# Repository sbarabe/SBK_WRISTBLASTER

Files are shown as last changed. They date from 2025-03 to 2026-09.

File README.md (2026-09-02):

# SBK_WRISTBLASTER
Arduino firmware, electronics, and 3D-printable parts for a custom Wrist Blaster prop inspired by *Ghostbusters: Frozen Empire*.

---
Work in progress :
- 3D model V2 parts list.
- Update electronics parts list.
- Update assembly guide for PCBs : PropCore One V2, BarDrive Max28 V1, BarMeter Sx28.
- New electronic board with SMD parts to make life easier...
- Polyphonic capability : dream board with polyphonic capability and embedded SDCard reader, player, amplifier, power circuits.
  
---
**2026-09-02 UPDATE**
- Firmware release v2.0.0.
- New schematic drawing with SBK PropCore One, BarDrive MAX28 and BarMeter Sx28 PCBs.
  
---

**2026-08-06 UPDATE**
- https://github.com/sbarabe/SBK_WRISTBLASTER/blob/main/README.md
- 3D model updated to V2, see 3D model README file for details.

---

<p>
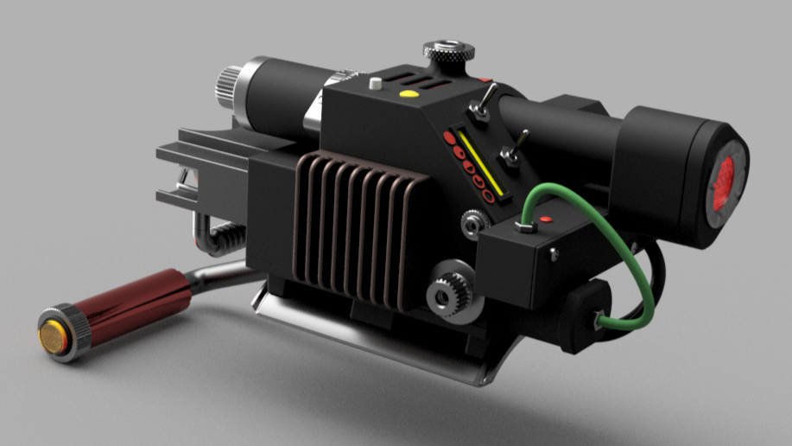
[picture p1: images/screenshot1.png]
  
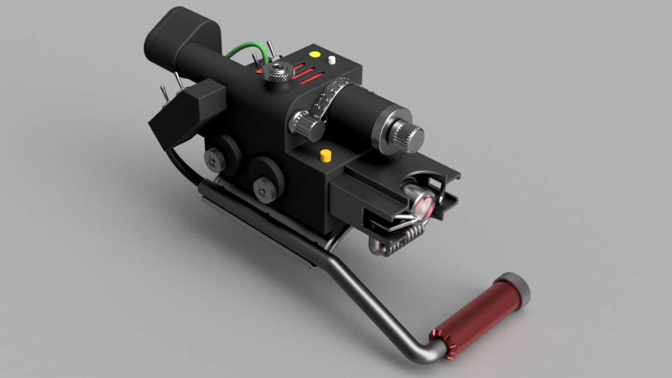
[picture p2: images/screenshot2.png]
  
</p>

Power Cell battery-pack options:

<p>
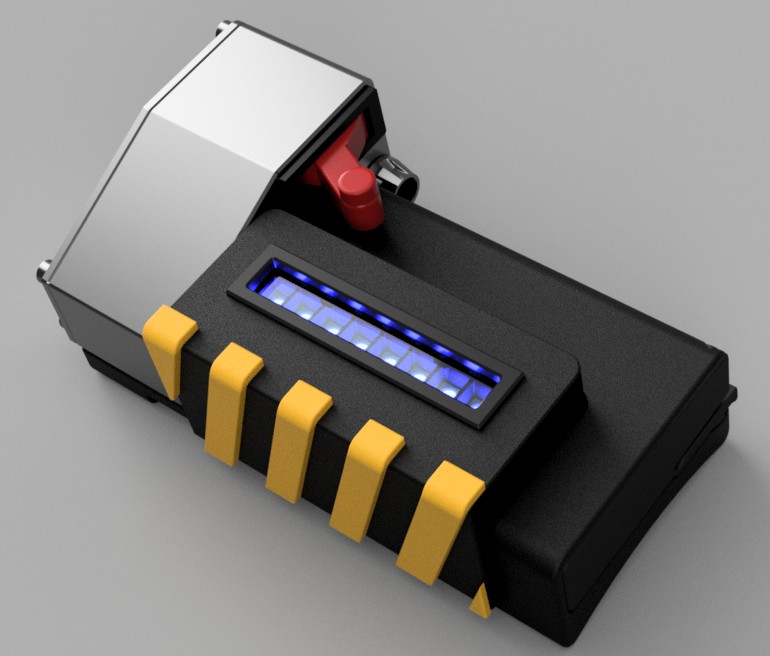
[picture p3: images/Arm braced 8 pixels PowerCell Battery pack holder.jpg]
8-pixel WS2812 Power Cell
  
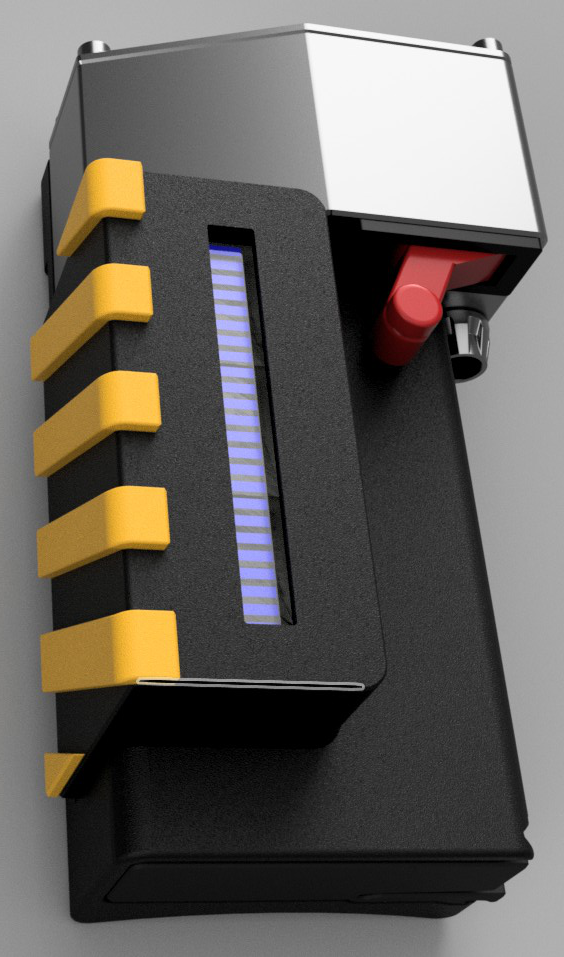
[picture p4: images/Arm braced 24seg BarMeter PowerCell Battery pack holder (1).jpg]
24-segment bar meter Power Cell
  
</p>

## Current Firmware Release

**Version 2.0.0**

This release introduces the new 2.0 engine architecture and migrates the latest firmware, configuration, and hardware definitions into the repository.

### Highlights in v2.0.0

- Revised power-up, Cyclotron, firing, overheat, venting, and shutdown sequences.
- Predefined pin mappings for several SBK controller boards, plus a custom-pin option.
- Panel bar meter support through either a MAX7219/MAX7221 or HT16K33 driver.
- Optional Power Cell using either:
  - an addressable WS2812 LED strip; or
  - a 24-segment bar meter driven by a MAX72xx or HT16K33.
- Power Cell WS2812 LEDs can share the main LED chain or use a separate output when supported by the selected board.
- Optional battery monitoring and low-battery shutdown on boards with a battery-sense input.
- Configurable switch logic, animation directions, segment mappings, potentiometers, illuminated fire button, and serial debugging.
- Support for DFPlayer communication through SoftwareSerial or the Nano Every hardware `Serial1` interface, depending on the selected board.
- Reusable Cyclotron and Power Cell animation schemes.
- External `SBK_Button`, `SBK_BarDrive`, `SBK_MAX72xx`, and `SBK_HT16K33` libraries replace the legacy bundled switch and bar-meter drivers.
- A lightweight bundled player engine replaces the external DFPlayer library dependency.
- Smoke support remains optional and experimental; it is disabled by default.

## Overview

`SBK_WRISTBLASTER_CORE` controls the prop's lighting animations, sound effects, switches, indicators, firing modes, heat simulation, and optional accessories.

The repository also includes 3D-printable parts, schematics, example sound effects, and resources for building the complete prop. The SBK PCBs are designed to fit the provided 3D model, but the firmware can also be adapted to other custom prop builds.

## Main Features

- **Sound effects:** DFPlayer Mini playback synchronized with prop states and animations.
- **Addressable lighting:** WS2812 animations for the firing tip, indicators, vent, Cyclotron, and optional Power Cell.
- **Panel bar meter:** Heat-level animation with configurable segment count, direction, and mapping.
- **Two firing modes:** Capture stream at regular Cyclotron power and burst firing at full power.
- **Heat and overheat simulation:** Heat accumulates while firing and cools while idle; extended firing triggers warning and venting sequences.
- **Party Mode:** Plays tracks stored in folder `/01` on the DFPlayer SD card.
- **Optional controls:** Volume and firing-hue potentiometers.
- **Optional battery monitoring:** Configurable battery chemistry, scaling, and low-voltage cutoff.
- **Standalone diagnostics:** The firmware can run without a working audio player, and serial debugging can be enabled in the configuration file.

## Supported Controller Configurations

Select exactly one controller definition in `SBK_WRISTBLASTER_CONFIG.h`.

> **Recommended controller:** The preferred and currently documented PCB for this firmware release is **SBK PropCore ONE Vx** (`SBK_PROPCORE_ONE_Vx`). Its schematic is available in the repository's [`Schematics`](https://github.com/sbarabe/SBK_WRISTBLASTER/tree/main/Schematics) folder. The other definitions are retained for compatibility with earlier boards or custom builds.

| Configuration | Supported MCU | Status and notes |
| --- | --- | --- |
| `SBK_PROPCORE_ONE_Vx` | Arduino Nano or Nano Every | **Preferred configuration.** Matches the currently available GitHub schematic and provides a separate WS2812 Power Cell output and battery-sense input. |
| `SBK_WRIST_BLASTER_PCB_V2` | Arduino Nano Every | Legacy board support; no dedicated Power Cell or battery-monitoring connection. |
| `SBK_WRIST_BLASTER_II_PCB_Vx` | Arduino Nano or Nano Every | Legacy board support; no dedicated Power Cell or battery-monitoring connection. |
| `SBK_PROPCORE_ONE_PLUS_Vx` | Arduino Nano Every | Alternate/extended configuration using hardware `Serial1`, a dedicated Power Cell bar meter interface, and a battery-sense input. |
| `CUSTOM_PINS_DEFINITION` | User-defined | Advanced custom builds; edit the dedicated custom section in `SBK_WRISTBLASTER_PINS_DEF.h`. |

## Hardware Requirements

> **Estimated electronics cost:** Makers sourcing the components themselves should expect approximately **$100–140 USD**, including a **7.2 V NiMH battery pack**. Actual cost depends on suppliers, shipping, component availability, and PCB quantities. This estimate excludes 3D-printing material, hardware, straps, and cosmetic parts.

See the electronic parts list in the `Resources` folder for complete details. A typical build uses:

- Arduino Nano Every.
- Genuine DFRobot DFPlayer Mini DFR0299 and a microSD card.
- Populated SBK controller PCB.
- Four miniature toggle switches, with the Intensify control optionally replaced by a push button.
- Five individual WS2812 pixels.
- Two 7-pixel WS2812 jewels.
- One 16 mm momentary fire button with a yellow LED, such as the R16-503.
- One 28-segment bar meter, such as the BL28-3000-Sx04Y.
- Compatible MAX7219/MAX7221 or HT16K33 bar meter driver hardware.
- One 2-inch, 3-5 W, 4-ohm speaker (check speaker footprint with the 3D model).
- A suitable 6–12 V power source; a 7.2 V NiMH flat pack is recommended for the provided battery holder.

Optional components include:

- One B10K potentiometer for volume **RECCOMENDED**.
- One B10K potentiometer for firing-strobe hue.
- An 8-pixel WS2812 Power Cell strip or a 24-segment Power Cell bar meter.
- Smoke and fan hardware for experimental smoke effects.

### SBK PCBs

- Main controller: **SBK Wrist Blaster PCB II** or **SBK PropCore ONE/ONE+**, according to the build.
- Common-cathode bar meter driver: **SBK BarMeter SK28 V1**.
- Common-anode bar meter driver: **SBK BarMeter SA28 V1**.
- 28-segment bar meter driver: **SBK BarDrive MAX28 V1** or **SBK BarDrive HT28 V1**.
- Optional 24-segment Power Cell bar meter and driver PCBs.

PCBs are produced in small batches and on demand. For availability, contact [SmartBuildsKits@gmail.com](mailto:SmartBuildsKits@gmail.com).

## Firmware Installation

### 1. Download the project

- Download the repository ZIP from [SBK_WRISTBLASTER](https://github.com/sbarabe/SBK_WRISTBLASTER), or clone the repository.
- Extract the files.

### 2. Install the sketch and bundled engine files

- Copy the `SBK_WRISTBLASTER_CORE` folder into your Arduino sketchbook.
- Move the bundled `SBK_WristBlaster_lib_V2_0_0` folder into the Arduino sketchbook `libraries` folder.

The final structure should resemble:

```text
Arduino/
├── libraries/
│   └── SBK_WristBlaster_lib_V2_0_0/
└── SBK_WRISTBLASTER_CORE/
    ├── SBK_WRISTBLASTER_CORE.ino
    ├── SBK_WRISTBLASTER_CONFIG.h
    └── SBK_WRISTBLASTER_PINS_DEF.h
```

### 3. Install external libraries

Using the Arduino IDE Library Manager, install:

- **Adafruit NeoPixel**
- **SBK Button**
- **SBK BarDrive**
- **SBK MAX72xx** or **SBK HT16K33**, according to the selected bar-meter driver

Install all dependencies requested by the Arduino IDE.

### 4. Configure the firmware

Open `SBK_WRISTBLASTER_CONFIG.h` and select exactly one PCB configuration:

```cpp
// Define exactly one:
// #define CUSTOM_PINS_DEFINITION
// #define SBK_WRIST_BLASTER_PCB_V2
// #define SBK_WRIST_BLASTER_II_PCB_Vx
#define SBK_PROPCORE_ONE_Vx
// #define SBK_PROPCORE_ONE_PLUS_Vx
```

Then review the remaining configuration sections for your build:

- switch and button type and logic;
- panel bar meter driver, direction, segment count, and mapping;
- WS2812 LED count and indexes;
- Power Cell type, driver, direction, and mapping;
- smoke effects, which are experimental and disabled by default;
- volume and firing-hue potentiometers;
- battery type, voltage scaling, and low-battery cutoff;
- DFPlayer volume, timing, and track durations;
- serial debugging.

> **Important:** Audio sequencing normally uses the track durations defined in `SBK_WRISTBLASTER_CONFIG.h`. Incorrect durations can desynchronize the sound and animations. BUSY-pin timing is available for experimentation but is not recommended by default.

Avoid modifying `SBK_WRISTBLASTER_CORE.ino`. For custom wiring, select `CUSTOM_PINS_DEFINITION` and edit only its dedicated section in `SBK_WRISTBLASTER_PINS_DEF.h`.

### 5. Compile and upload

- Open `SBK_WRISTBLASTER_CORE.ino` in the Arduino IDE.
- Select the board that matches the chosen controller configuration.
- Select the correct serial port.
- Compile and upload the sketch.

## Sound Effects and SD Card Setup

The provided example sound effects match the track numbers and default durations in the firmware configuration.

The DFPlayer identifies root-folder tracks by their copy order rather than reliably by filename. Start with a freshly formatted microSD card and copy the required root tracks to it one at a time, in numerical order.

Place additional music tracks in folder `/01`; these are used by Party Mode.

If you replace or edit a sound file, update its duration in `SBK_WRISTBLASTER_CONFIG.h` so the corresponding animation remains synchronized.

### Sound-effects disclaimer

The example sound effects are derived from *Ghostbusters* films and games and remain the property of their respective copyright holders. They are provided as edited examples for this fan project. You are responsible for ensuring that your use complies with applicable copyright law.

## Controls and Operation

- **Main Power:** Turns the blaster on or starts the shutdown sequence.
- **Cyclotron Power:** Starts the Cyclotron and enables regular-power Capture firing.
- **Activate:** Raises the Cyclotron to full power and enables Burst firing.
- **Fire Button:** Starts the firing sequence for the currently selected power level.
- **Intensify:** Enters or exits Party Mode. It can be configured as either a push button or a switch.
- **Party Mode navigation:** Short-press Fire for the next track; long-press Fire for the previous track.
- **Overheat:** Repeated Burst shots or a long Capture stream can trigger an overheat warning, venting sequence, and system restart.

When experimental smoke support is compiled in, hold the Fire button while the blaster is in the Power Off state to view or change the smoke-enable status. The top white indicator displays green when enabled and red when disabled.

## 3D Model Design Choices

The model aims for the rugged, prototype-like appearance of the *Frozen Empire* prop while making several practical changes:

- The Intensify control may be built as a switch because its original push-button position is difficult to reach while the blaster is worn on the right arm.
- The straps pass between the main body and the arm-brace plate, leaving more internal room for the electronics and speaker.
- The arm-brace plate is curved to accept a 3/8-inch copper-pipe handle secured through the plate holes.
- The indicator lenses use modern, readily available parts.
- The fire button includes a yellow indicator LED.
- The front knob and Clippard-valve knob can optionally control volume and firing hue.

See the README in the `3D model` folder for model-specific information and revision notes.

## Schematics

Schematics in the `Schematics` folder show the wiring for the supported SBK controller, BarDrive, and BarMeter PCBs. Confirm that the schematic revision matches your controller selection and firmware configuration before assembly.

## Demo Video

🎥 [Watch the demo video](https://drive.google.com/file/d/1tK8gQD61fCHybJHeq_SOud1DNxneKH4g/view?usp=sharing)

## Contributing

Pull requests are welcome. Please fork the repository, test your changes on the intended hardware, and describe the controller and configuration used for testing.

## License

- The firmware source files identify the code as licensed under the **MIT License**.
- The repository-level `LICENSE` file covers the remaining project material under **Creative Commons Attribution 4.0 International (CC BY 4.0)**.
- Included or referenced *Ghostbusters* media remains the property of its respective copyright holders and is not relicensed by this project.

See the repository `LICENSE` file and the headers of individual source files for the terms that apply to each item.

## Author and Collaborator

### Author: Samuel Barabé

Engineer and maker focused on embedded programming, electronics, 3D design, and immersive props.

### Collaborator: David Miyakawa

Graphic designer and *Ghostbusters* enthusiast who contributed to sound design, prop appearance, screen-inspired workflow, assembly, painting, and finishing.

## Contact and Support

- Email and PCB inquiries: [SmartBuildsKits@gmail.com](mailto:SmartBuildsKits@gmail.com)
- GitHub: [sbarabe](https://github.com/sbarabe)
- Donations: [PayPal](https://paypal.me/sbarab?country.x=CA&locale.x=fr_CA)

---

Enjoy building your Wrist Blaster!

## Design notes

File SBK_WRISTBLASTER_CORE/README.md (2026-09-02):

# SBK_WRISTBLASTER_CORE

Arduino firmware for controlling the lights, sound effects, switches, indicators, and animation sequences of the SBK Wrist Blaster replica or other custom props.

## Current Release

**Version 2.0.0**

This release migrates the firmware to the new 2.0 engine architecture:

- Reworked the core state machine, configuration, and pin definitions.
- Added reusable Cyclotron and Power Cell animation schemes.
- Replaced the legacy switch handling with the `SBK_Button` library.
- Replaced bundled bar-meter drivers with the `SBK_BarDrive`, `SBK_MAX72xx`, and `SBK_HT16K33` libraries.
- Replaced the external DFPlayer dependency with the bundled lightweight player engine.
- Updated the LED-strip, vent, firing-rod, indicator, smoke, battery-monitoring, and Power Cell engines.

The firmware retains the features introduced in previous versions, including:

- Support for multiple SBK PCB configurations and custom pin assignments
- DFPlayer Mini sound playback
- WS2812 lighting effects and animation sequences
- Panel bar-meter support using either a MAX7219/MAX7221 or HT16K33 driver
- Configurable 28-segment bar-meter mapping and animation direction
- Optional Power Cell using either:
  - An addressable WS2812 LED strip
  - A 24-segment bar meter
- Optional battery-voltage monitoring on supported boards
- Configurable switches, buttons, potentiometers, and indicator outputs
- Serial debugging
- Compile-time configuration checks

Most users should only need to modify `SBK_WRISTBLASTER_CONFIG.h`.

The main file, `SBK_WRISTBLASTER_CORE.ino`, contains the state machine and core operating logic and should normally remain unchanged.

## Supported Hardware Configurations

The following predefined pin configurations are available:

- `SBK_WRIST_BLASTER_PCB_V2`
- `SBK_WRIST_BLASTER_II_PCB_Vx`
- `SBK_PROPCORE_ONE_Vx`
- `SBK_PROPCORE_ONE_PLUS_Vx`
- `CUSTOM_PINS_DEFINITION`

The firmware supports the Arduino Nano Every and ATmega328-based Nano targets, subject to the enabled feature set and available memory.

Exactly one hardware configuration must be selected in `SBK_WRISTBLASTER_CONFIG.h`.

## Required Arduino Libraries

Install the following libraries using the Arduino IDE Library Manager:

- [Adafruit NeoPixel](https://github.com/adafruit/Adafruit_NeoPixel)
- [SBK Button](https://github.com/sbarabe/SBK_Button)
- [SBK BarDrive](https://github.com/sbarabe/SBK_BarDrive)
- [SBK MAX72xx](https://github.com/sbarabe/SBK_MAX72xx) when using a MAX72xx bar-meter driver
- [SBK HT16K33](https://github.com/sbarabe/SBK_HT16K33) when using an HT16K33 bar-meter driver

The firmware also uses the standard Arduino `Wire` and `SoftwareSerial` libraries.

The project-specific engine files are included in the `SBK_WristBlaster_lib_V2_0_0` folder.

## Installation

1. Download or clone the complete [SBK_WRISTBLASTER repository](https://github.com/sbarabe/SBK_WRISTBLASTER).

2. Copy the `SBK_WRISTBLASTER_CORE` folder into your Arduino Sketchbook folder.

3. Copy the included `SBK_WristBlaster_lib_V2_0_0` folder into your Arduino Sketchbook `libraries` folder.

4. Install the required external Arduino libraries listed above.

5. Open `SBK_WRISTBLASTER_CORE.ino` in the Arduino IDE.

6. Open `SBK_WRISTBLASTER_CONFIG.h` and select the correct PCB configuration:

   ```cpp
   // Define exactly one:
   // #define CUSTOM_PINS_DEFINITION
   // #define SBK_WRIST_BLASTER_PCB_V2
   // #define SBK_WRIST_BLASTER_II_PCB_Vx
   #define SBK_PROPCORE_ONE_Vx
   // #define SBK_PROPCORE_ONE_PLUS_Vx

7. Work through the configuration file and adjust the available options to match your build, including:

   - Switch and button types and logic
   - Panel bar-meter driver type, segment mapping, and animation direction
   - Smoke-effect support—currently a beta feature that has not yet been tested with a real smoke device
   - Volume potentiometer support
   - Firing-rod hue potentiometer support
   - Power Cell type and configuration, if installed
   - Battery-voltage sensing and low-voltage protection options
   - LED indexes and animation directions
   - Sound-track durations and audio timing
   - Serial debugging

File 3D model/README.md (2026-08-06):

# SBK WRISTBLASTER 3D MODEL
---
**2026-08-06 UPDATE**

3D model updates to **V2**.
- Some interferences fixed.
- Fire Rod LEDs jewel distance from lens was adjusted for better luminosity, a LEDs holder (part #34) was created for this, Rod Box and Lens Holder were adapted too.
- Handle was corrected for 3/8 copper pipe, about 10mm outside diameter.
- Gunbox and base plate modified for last electronic PCBs version.
- Changed parts are marked as V2.
- Some previous electronics PCBs may not fit without model modifications
---
3D model for 3D printing of a *Ghostbusters: Frozen Empire* inspired Wrist Blaster replica.

The 3D model provided is part of this project: [SBK_WRISTBLASTER](https://github.com/SmartBuildsKits/SBK_WRISTBLASTER).

The SBK PCBs are specifically designed to fit this model but can also be used in other designs.

See the **3D printed parts list** and **Other parts list** for details.

I keep a small stock of non-printed parts for personal uses. If you're having trouble sourcing a specific component, feel free to reach out—I might be able to help. **Contact me via email for inquiries**.

Screenshot of PCB design Screenshot of PCB design

## License

Shield: [][cc-by]

This work is licensed under a
[Creative Commons Attribution 4.0 International License][cc-by].

[][cc-by]

[cc-by]: http://creativecommons.org/licenses/by/4.0/
[cc-by-image]: https://i.creativecommons.org/l/by/4.0/88x31.png
[cc-by-shield]: https://img.shields.io/badge/License-CC%20BY%204.0-lightgrey.svg

This means:

✅ You are free to share (copy and redistribute) and adapt (remix, transform, build upon) the material.

❌ Commercial use is prohibited without the author's consent.

✅ You must give appropriate credit and link to the original project.

For more details, see the full license text: [CC BY 4.0](http://creativecommons.org/licenses/by/4.0/).

## Contact

📧 **Email:** [SmartBuildsKits@gmail.com](mailto:SmartBuildsKits@gmail.com)

🌐 **Website:** [https://github.com/SmartBuildsKits](https://github.com/SmartBuildsKits)

## Support

💸 To keep this project and keep development going, you can **acquire a PCB** or **donate via PayPal**: [Donate via PayPal](https://paypal.me/sbarab?country.x=CA&locale.x=fr_CA).

💻 **Inquiries** can be sent to [SmartBuildsKits@gmail.com](mailto:SmartBuildsKits@gmail.com).

---

Enjoy building your wrist blaster! 🚀💥

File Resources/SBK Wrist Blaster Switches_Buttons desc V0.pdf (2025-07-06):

# SBK Wrist Blaster switches/buttons descriptions

INTENSIFY SWITCH/BUTTON:
OFF = Party Mode OFF
ON = Party Mode ON
Play music from /01 folder. You can play next with fire button short press, or previous with long press.
Party Mode only works when Power is On but Cyclotron is OFF.

ACTIVATE SWITCH:
OFF = Capture Mode
Keep firing when firing button is pressed until overheat, about 20-25 seconds.
Cooldown while not firing. Heat level displayed on bar meter : fuller the bar, hotter it is.
ON = Burst Mode
Fire a short burst when Fire Button is pressed.
You can fire rapidly 5 shots before overheating.
There is a cooldown mechanic so waiting a little between shots make it possible to fire many shots without
overheating.

CYCLOTRON SWITCH:
OFF = Cyclotron OFF
ON = Cyclotron ON

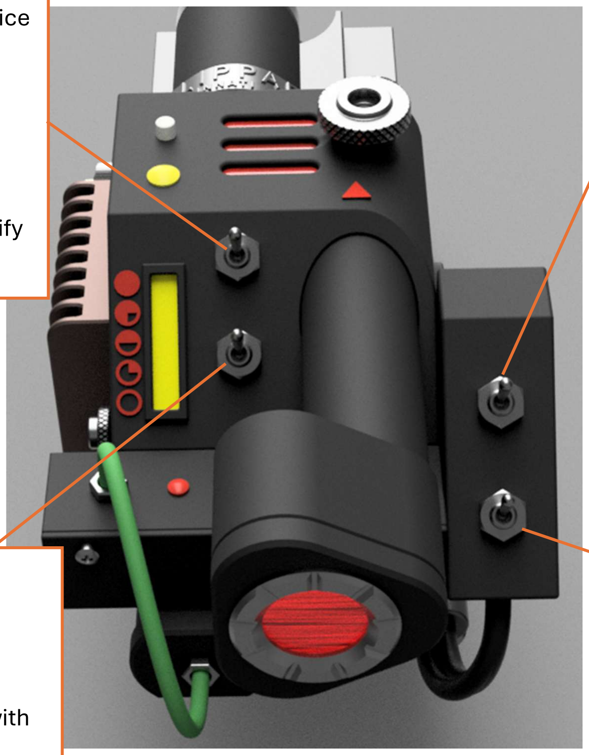
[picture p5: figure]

While cyclotron ON, you can fire with fire button. Fire type depends on Activate switch state for Capture Mode or Burst Mode.

POWER SWITCH:
(software power, not hardware)
OFF = Power OFF
While in power o, can
enable/disable optional smoke device with fire button.
ON = Power ON
Power the wrist blaster (some leds eects) but cannot fire without turning on the cyclotron.
Can goes in Party Mode with Intensify button/switch.

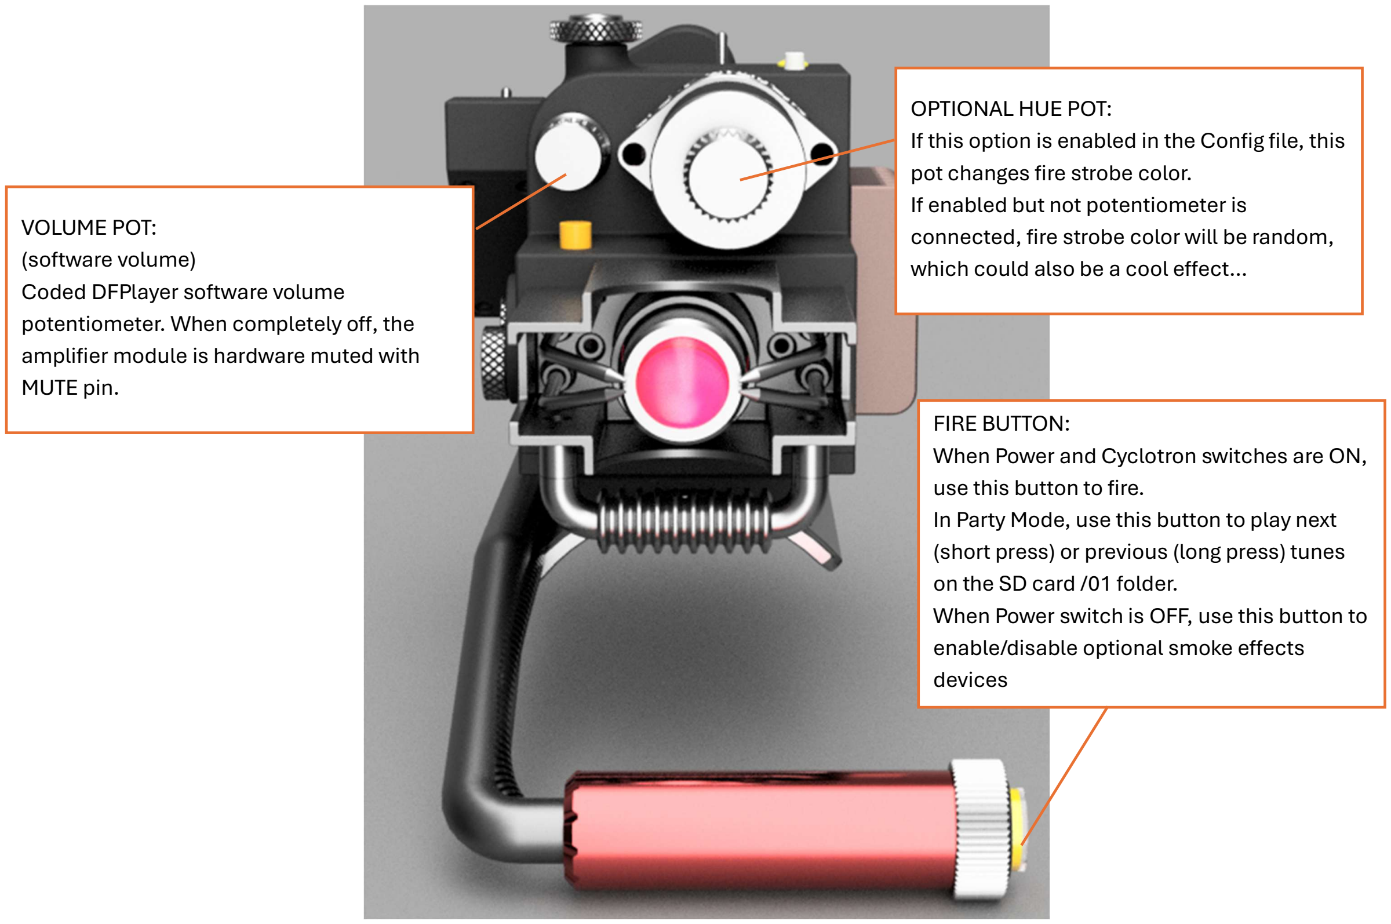
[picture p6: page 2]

VOLUME POT:
(software volume)
Coded DFPlayer software volume potentiometer. When completely o, the amplifier module is hardware muted with MUTE pin.

OPTIONAL HUE POT:
If this option is enabled in the Config file, this pot changes fire strobe color.
If enabled but not potentiometer is connected, fire strobe color will be random, which could also be a cool eect…

FIRE BUTTON:
When Power and Cyclotron switches are ON, use this button to fire.
In Party Mode, use this button to play next (short press) or previous (long press) tunes on the SD card /01 folder.
When Power switch is OFF, use this button to enable/disable optional smoke eects devices

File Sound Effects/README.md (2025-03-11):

# Sound Effects

Sound effects examples are provided for this project : [SBK_WRISTBLASTER_CORE](https://github.com/SmartBuildsKits/SBK_WRISTBLASTER_CORE). They fit the firmware track numbers and lengths defined in the config file. Each sound effect should be placed in the correct order on the Player's SD card root folder. Additional tracks can be placed in the "/01" folder of the SD card; these tracks will play in Party Mode.

**Disclaimer**: The sound effects in this project are derived from the *Ghostbusters* movies and video games, which are commonly available within the *Ghostbusters* community. These sounds are not owned by me, and the original works are copyrighted by their respective owners. The sound effects here have been edited, cut, and remixed for use in this project. No copyright infringement is intended. It is your responsibility to ensure that your use of these sound effects does not violate copyright laws.

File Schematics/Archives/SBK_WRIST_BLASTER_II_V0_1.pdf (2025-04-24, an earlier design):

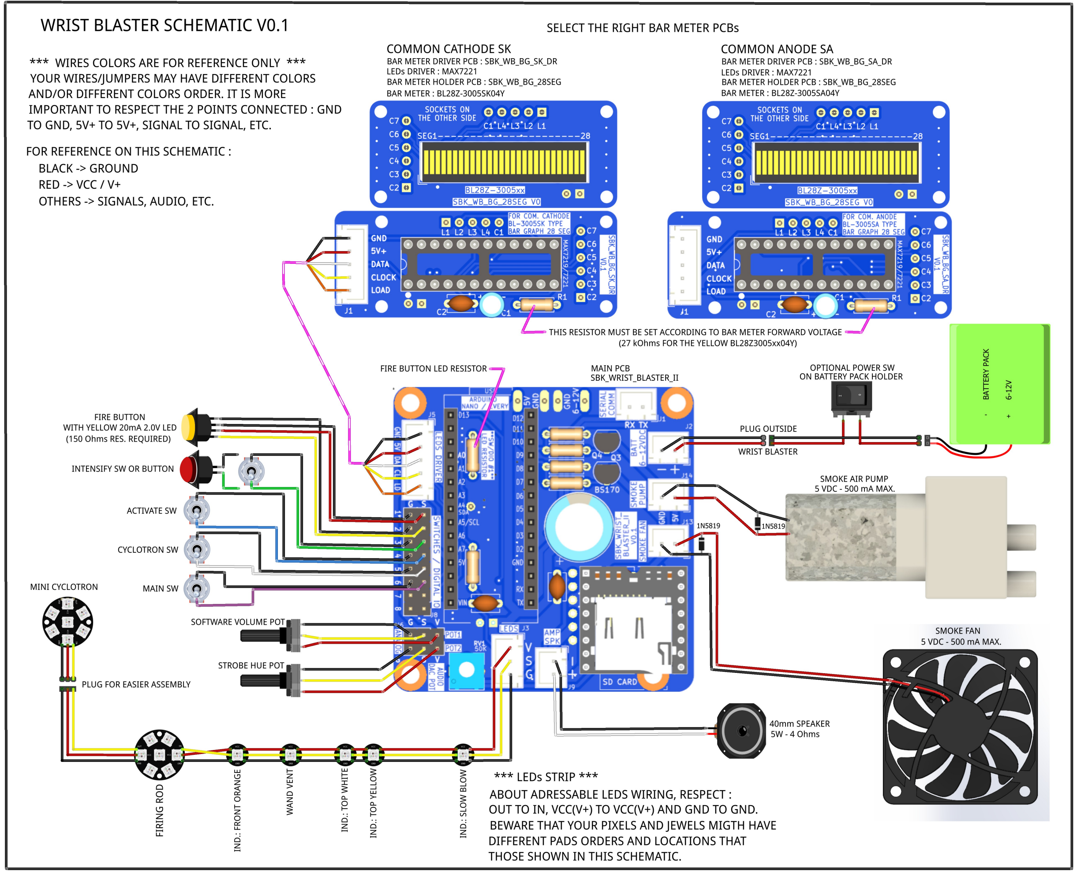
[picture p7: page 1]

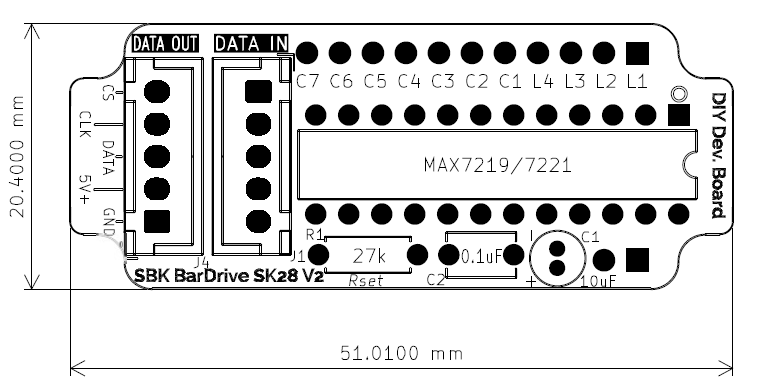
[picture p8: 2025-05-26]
Schematics/SBK PCBs/SBK BarDrive SK28 V2.png

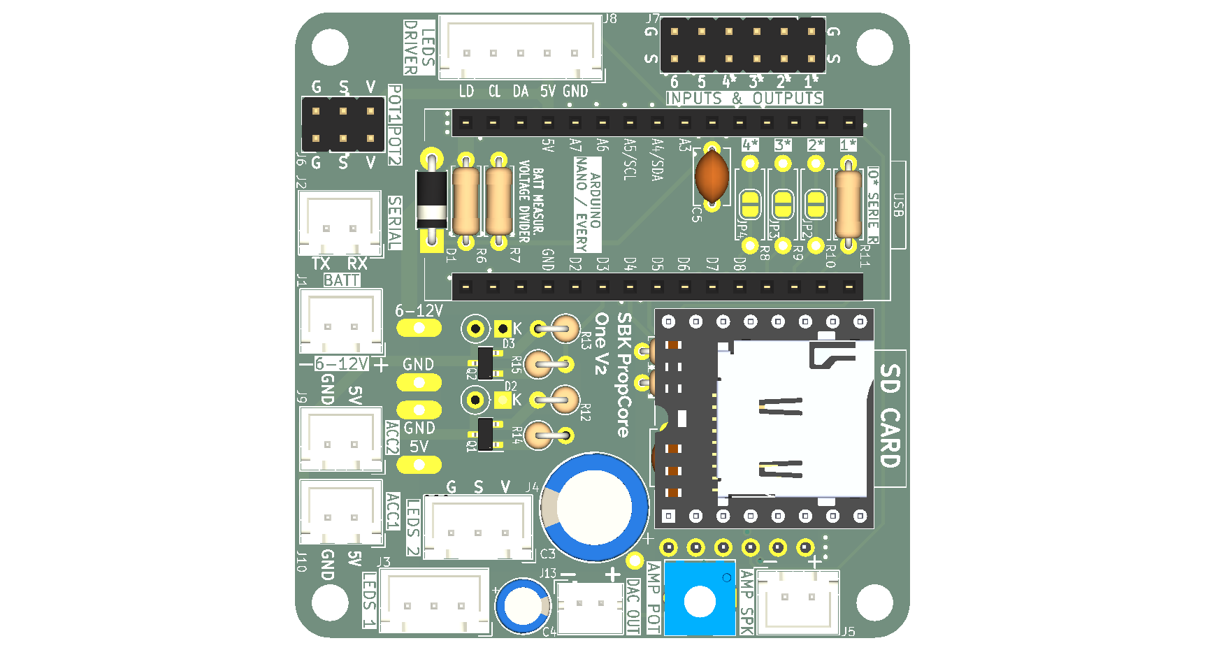
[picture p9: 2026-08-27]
Schematics/SBK PCBs/SBK PropCore One V2.png

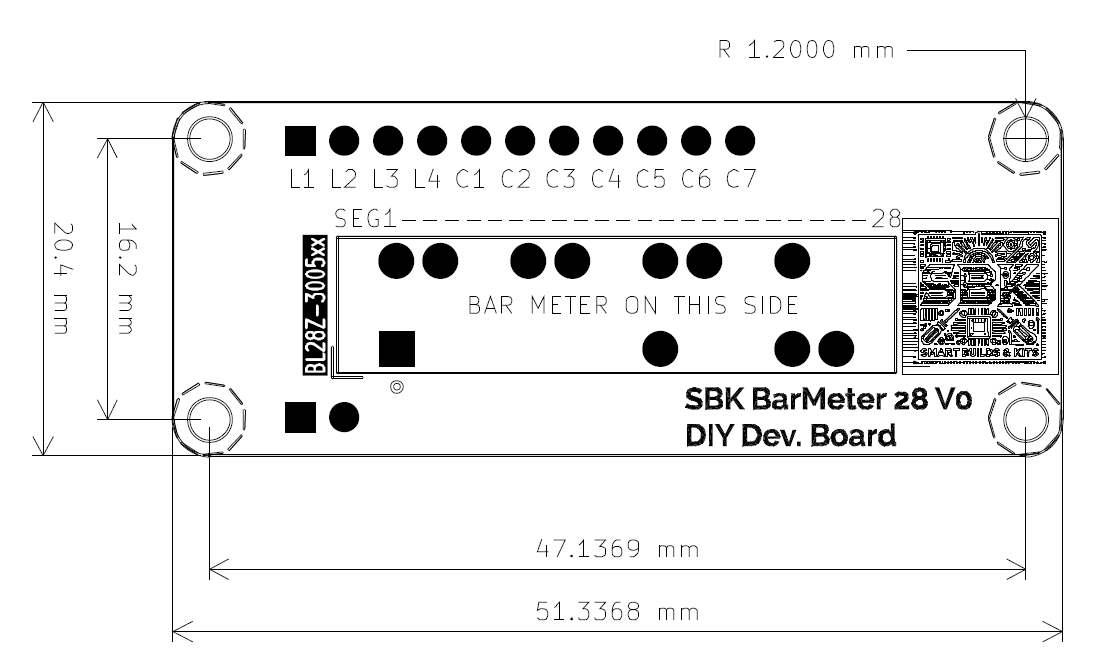
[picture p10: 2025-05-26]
Schematics/SBK PCBs/SBK BarMeter 28 V0.png

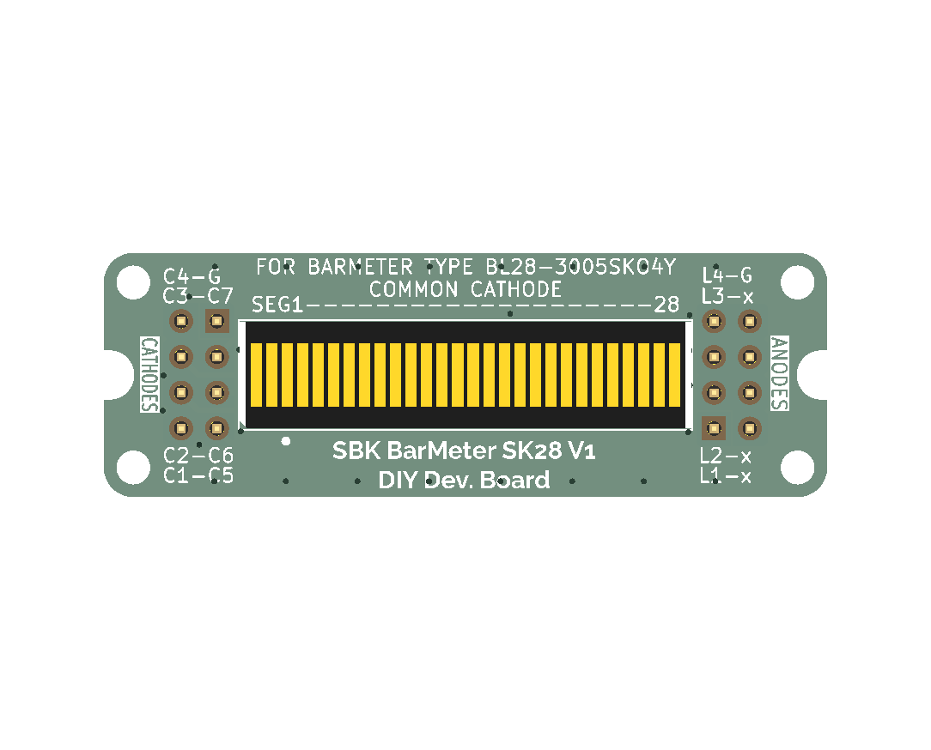
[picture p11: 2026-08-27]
Schematics/SBK PCBs/SBK BarMeter SK28 V1.png

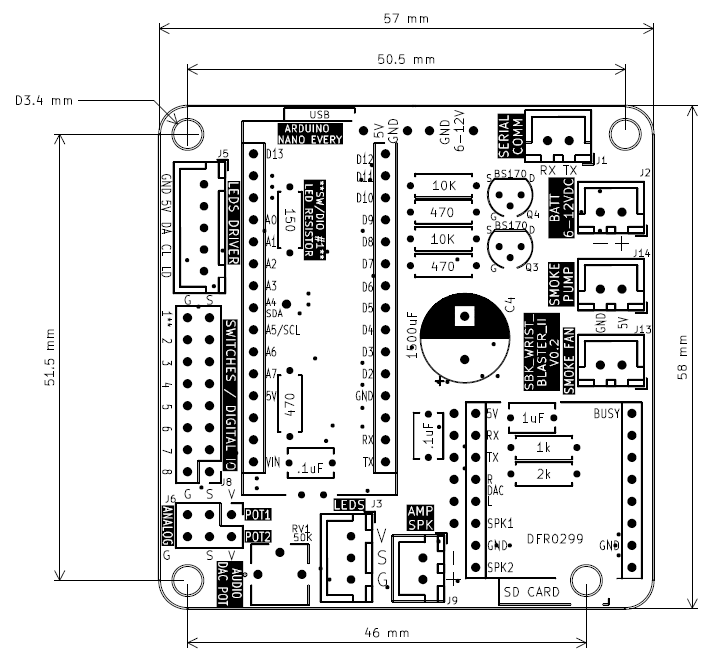
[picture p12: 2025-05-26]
Schematics/SBK PCBs/SBK_WRIST_BLASTER_II V0.2.png

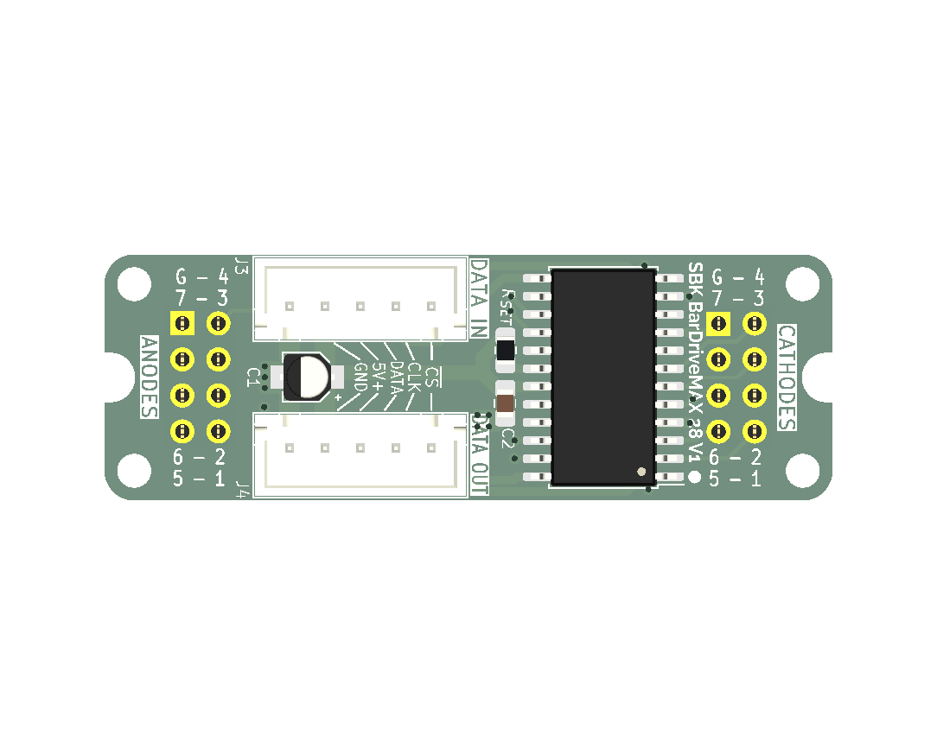
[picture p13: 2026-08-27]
Schematics/SBK PCBs/SBK BarDriveMAX 28 V1.png

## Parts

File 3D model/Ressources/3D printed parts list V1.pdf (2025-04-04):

Part | Comments
01-Rod box.stl
02.1-Gunbox.stl | You can either print the Gunbox in one piece or, for better accuracy, print all the 4 pieces and glue the supports inside the Gunbox.
02.2-Gunbox top indicators leds support.stl
02.3-Gunbox Bar graph support.stl
02.4-Gunbox Front indicator led support.stl
02-Gunbox ONE PIECE.stl
03-Gunbox base plate C_D version | For arm brace plate versions C/D
04-Arm brace D version.stl | Curve on both side for 3/8 copper pipe handle
04-Arm brace D-trunk version.stl | Curved only on one side for 3/8 copper pipe handle
05-Gunbox front panel.stl
06-Gunbox front panel cover.stl
07-Gunbox front side panel.stl
08-Gunbox front side panel bottom.stl
09-Gunbox front panel side connector.stl
10.1-Front guard sleeve.stl | You can either print the Front Guard Heat Sink in one piece or print all the pieces and glue them togheter. Beware you need 2x side 1 and 2x side2…
10.2-Front guard quarter side 1.stl
10.3-Front guard quarter side 2.stl

### 10.4 Front Guard heat sink.stl

10-Front guard ONE PIECE.stl
11-Gunbox front valve.stl
12-Gunbox back panel POT knob.stl | Fits on a B10K 15mm shaft potentiometer
13-Gunbox side double knob.stl
14-Gunbox main side large knob.stl
15-Gunbox main side small knob.stl
16-Gunbox top knob.stl
17B-Clippart valve body - PUMP.stl | With inside cavity for mini pump
18B-Clippart valve knob - PUMP.stl | Fits on a B10K 15mm shaft potentiometer
19A.1-Mini cyclotron tube 80mm.stl | Can be a standard 3/4inch PVC electrical conduit. The ring fits perfectly on it, glue the ring to conduit with epoxy
19B.1-Mini cyclotron tube 95mm (longer for smoke device).stl
19.2A_.2B-Cyclotron tube filets ring.stl
19C-Mini cyclotron tube 80mm with ring.stl

19D-Mini cyclotron tube 95 with ring (longer for smoke device).stl
20-Mini cyclotron.stl
21-Mini Cyclotron lens cover.stl
22A-Gunbox Heatsink.stl | If you don't want the fan option now and later, you could use this file…
22B-Gunbox Heatsink with fan.stl | With inside cavity for a 3006 or 3007 fan
23-Fire handlebutton cap.stl
25B-Fire Handle body.stl | Fits astandard 3/8 copper pipe
26-strob lens 23mm.stl | Should be bougth, not print…
27-Fire rod lens holder.stl
28-Pneumatic fitting slim.stl
29-Vent lens.stl | Print in translucent material
30-Gunbox Side Panel Wire Clip.stl
*31.1A Battery pack holder witch KCD1 switch.stl | Model A : simple battery pack holder with switch
*31.1B Battery pack holder and 8seg PowerCell.stl | Model B : battery pack holder with Powercell 8pixel stick and thunder switch…
*31.1C Battery pack holder and 8seg PowerCell.stl | Model C : battery pack holder with Powercell 24seg bar meter and thunder switch…
*31.2A Battery pack holder COVER.stl | fits model A only
*31.2B_C Battery pack holder COVER.stl | fits models B and C
*31.3B Powercell switch back cover.stl | fits model B only
*31.3C Powercell switch back cover.stl | fits model C only
*31.4B_C Cable gland.stl | fits models B and C

SBK Wrist Blaster Model V1 3D printed parts

If you are printing the tube, then use one of these files. No need to print the ring.

Page 1

Part | Comments
*31.5B Powercell lens rim cover.stl | fits model B only
*31.6B Powercell 9x57x2mm lens.stl | fits model B only, clear or frosted acrylic, 2mm, not to be printed
*31.6C Powercell 9x63x2mm lens.stl | fits model C only, clear or frosted acrylic, 2mm, not to be printed
32A Main PCB holder (SBK_WRISTBLASTER II PCB).stl | Select for your main PCB model

SBK Wrist Blaster Model V1 3D printed parts

32B Main PCB holder (SBK PropCore One_OnePlus).stl
32C Main PCB holder (for obsolete gunbox base plate model).stl
33A Handle 3_8 copper tubing hollow (reference).stl
33B Handle 3_8 copper tubing solid (reference).stl
* Battery holder optional

Not to be printed, for reference only. Adjust to your arm length for a confortable position.

Page 2

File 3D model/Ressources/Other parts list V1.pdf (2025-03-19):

Part | Description | Qty | Manufacturer | Parts numbers | Supplier
Front orange indicator | Amber plastic lens | 1 | VCC | CLF_280_ATP | Digikey or Mouser
Slow blow indicator | Red plastic lens | 1 | VCC | SMB_200_RTP | Digikey or Mouser
Top white indicator | Clearplastic lens | 1 | VCC | SML_190_CTP | Digikey or Mouser
Top Yellow Indicator | Yellow plastic lens | 1 | VCC | CMC_321_YTP | Digikey or Mouser
Blaster handle | bent 3/8 copper pipe, about 300-350mm (12"-14") long | 1
Arm brace straps with buccle | 20-25mm wide, about 350-400mm (14"-16") long | 2
Firing rods | Common nail, 2-1/2" long | 4
Firing lens | Acrylic clear convexe lens, 23mm diameter | 1 | | | Amazon, Aliexpress
Cyclotron lens | Acrylic clear disc 25mm diameter, 2.5mm thickness | 1 | | | Amazon, Aliexpress
Clippard Valve fastener | M5-20mm bolt and nut | 2 | | | Amazon, Aliexpress, Hardware store
Firing Rod Box fastener | M3-8mm bolt and nut | 2 | | | Amazon, Aliexpress, Hardware store
Top knob fastener | M4-8 Socket Cap Screw tapping screw - SS | 1
Side double knobs fastener | M3-6mm Socket Cap Screw tapping screw - SS | 2
Side knob fastener | M3-14mm Socket Cap Screw tapping screw - SS | 1 | | | Amazon, Aliexpress
Side small knob fastener | M2-6mm Socket Cap Screw tapping screw - SS | 1 | | | Amazon, Aliexpress
Knobs washer (to put between knobs and body) | M4 washer | 5
Main PCB fastener | M3-16mm Socket Cap Screw tapping screw - SS | 4 | | | Amazon, Aliexpress
Arm brace plate fastener | M3-12mm flat head tapping screw - SS | 6 | | | Amazon, Aliexpress
Front valve fastener | M3-12mm Socket Cap Screw tapping screw - SS | 1 | | | Amazon, Aliexpress
Front panel fasteners | M3-8mm Round Head Screw tapping screw | 2 | | | Amazon, Aliexpress
Fan fasteners | M3-10mm Socket Cap Screw tapping screw - SS | 4 | | | Amazon, Aliexpress
Base plate fasteners | M3-8mm Socket Cap Screw tapping screw - SS | 6 | | | Amazon, Aliexpress
Bar meter PCBs sandwich fasteners | M2-10mm Socket Cap Screw tapping screw - SS | 4 | | | Amazon, Aliexpress
Heat sink fasteners | M2-8mm Socket Cap Screw tapping screw - SS | 4 | | | Amazon, Aliexpress
Led pixel fasteners | M2-6mm Socket Cap Screw tapping screw - SS | 12 | | | Amazon, Aliexpress
Component fasteners | M3-10mm Socket Cap Screw tapping screw - SS | xx | | | Amazon, Aliexpress
Component fasteners | M3-8mm Socket Cap Screw tapping screw - SS | xx | | | Amazon, Aliexpress
Component fasteners | M3-6mm Socket Cap Screw tapping screw - SS | xx | | | Amazon, Aliexpress

SBK Wrist Blaster Model V1 others parts

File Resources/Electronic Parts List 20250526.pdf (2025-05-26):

SBK WRIST BLASTER : Electronic parts list | 2025-05-26
Description | Dimensions / Value | Qté | Supplier | Part Number | Comments
PCB | 57 x 58 x 1.6mm | 1 | SBK | SBK_WRIST_BLATER_II_PCB V0.2 | Email me for inquiries : SmartBuildsKits@gmail.com
Arduino Nano Every with 2x male header 1x15 | Arduino Nano Every | 1 | Digikey, Mouser | ABX00033
DFPlayer Mini with 2x male header 1x08 | DFR0299 | 1 | Digikey, Mouser | DFR0299
Micro SD card | Recommanded Class 4 128 MB min. (for sound effects and a few music tracks only) 16 GB max (unlimited music tracks !) | 1 Amazon | | | Size up to your taste : for the sound effects and few tracks, a 128MB is sufficient. If you want to put a lot of music tracks, well you can go up to 16GB.
Power supply module | DFR0753 , DC-DC Buck Converter 6~14V to 5V/8A Replica can be found under the name CK1408… | 1 | Digikey or Mouser | DFR0753
LTK5128 5W Class D mono Amp module | 12x15x1.6mm | 1 | Amazon | 5W 5128 Class D mono amplifier module

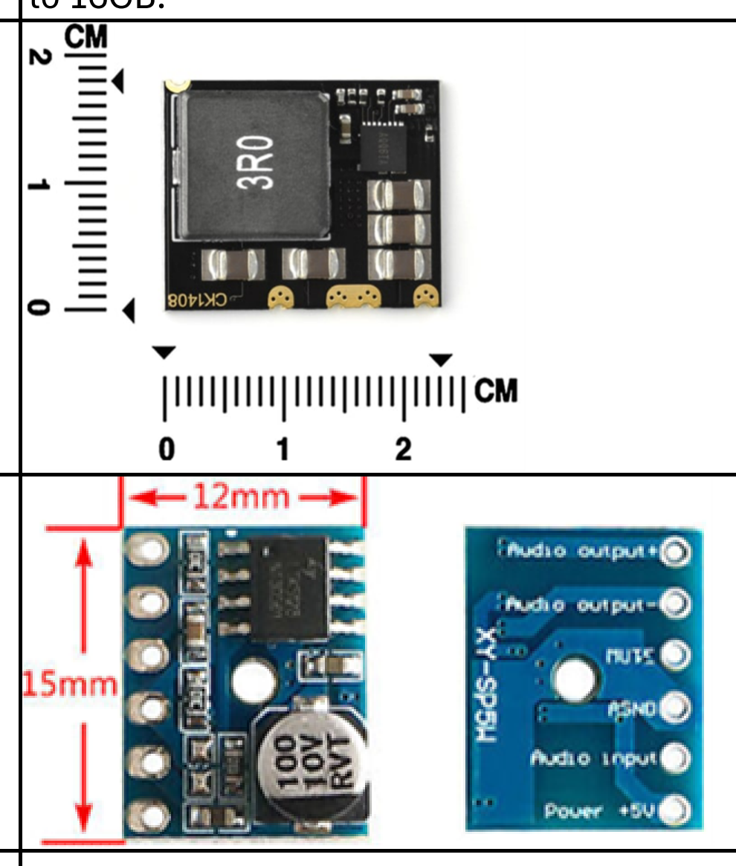
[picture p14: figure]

Female header | Female 2.54mm 1x08 | 2 | Amazon | Male and femal 2.54 headers kit | You can buy a kit on Amazon to cover all your needs for this
Female header | Female 2.54mm 1x15 | 2
Male header | Male 2.54mm 1x06 | 1
Male header | Male 2.54mm 1x02 | 1
Male header | Male 2.54mm 1x01 | 3
Male header | Male 2.54mm 2x08 | 1
Male header | Male 2.54mm 2x03 | 2
JST XH254 terminal male plug | JST-XH 2.54mm male terminal, THT, 1x05 | 1 | Amazon | JST-XH 2.54mm kit | You can buy a kit on Amazon to cover all your needs for this project.
JST XH254 terminal male plug | JST-XH 2.54mm male terminal, THT, 1x03 | 1
JST XH254 terminal male plug | JST-XH 2.54mm male terminal, THT, 1x02 | 5
Resistor 1/4W | 10k THT 1/4W | 2 | Amazon | resistors kit | You can buy a kit on Amazon to cover all your needs for this project.
| 2k THT 1/4W | 1
| 1k THT 1/4W | 1
| 470 THT 1/4W | 3
| 150 THT 1/4W (for fire button yellow led) | 1
Ceramic capacitor | 0.1uF - 5mm between pins | 2 | Digikey | 0.1uF Ceramic Capacitor | Beware that some ceramic capacitors on Amazon or Aliexpress are fake or out of spec.
Ceramic capacitor | 1uF - 5mm between pins | 1 | Digikey | 1uF Ceramic Capacitor
Low ESR Electrolityc Capacitor | 220 uF 10V 6mm dia x 7mm, 2.5mm between pins | 1 | Digikey, Mouser, Amazon | 220 uF 10V 6mm dia x 7mm | This capacitor is under the board, there is other size, but the 7mm high is more convenient to fit under the board.
Low ESR Electrolityc Capacitor | 1500 uF 10V 10mm dia x 17mm, 5mm between pins | 1 | Digikey, Mouser, Amazon | 1500 uF | Various size available, but max diameter is 13mm.
trimer pot | 50K, 3362P Serie, P503, THT | 1 | Amazon, Mouser, Digikey | trim pot kit
MOSFET | BS170 TO-92 NMOS - DGS (Drain-Gate-Source) | 2 | Amazon, Mouser, Digikey | BS170 TO-92 | Be aware that some Chineese knockouts are not DGS but SGD… So test your MOSFET before soldering them. The SGD can still be used, you need to rotate them 180° on the pcb regarding to silkscreen marking...
Flyback diode | 1N5819 THT | 2 | Amazon, Mouser, Digikey | 1N5819 | Not on the PCB but should be installed accross 5V and GND of pump and fan for the smoke effect. Could be solederd under the PBC on the JST-XH pins below the board. See schematics for details.

SBK_WRIST_BLATER_II_PCB V0.2

Page 1

Description | Dimensions / Value | Qté | Supplier | Part Number | Comments
Bar meter driver PCB | 54.1*20.4mm | 1 | SBK | SBK BarDrive xx28 V2 | xx = SA -> Common Anode xx = SK -> Common Cathode
Bar meter PCB | 47.2x20.4mm | 1 | SBK | SBK BarMeter 28 V0 | Fits both SA or SK bar meter
Leds driver chip | MAX7221 DIP-24 | 1 | Digikey, Mouser, Amazon | MAX7221 DIP-24 | Can find knock off on Amazon or Aliexpress..
Bar Meter 28segments yellow | BL28-3005xx04Y | 1 | Aliexpress | BL28-3005xx04Y | Must fit your driver PCB : xx = SA -> Common Anode xx = SK -> Common Cathode Can find various sellers on Aliexpress, I do not recommand one in particular…
JST XH254 terminal male plug | JST-XH 2.54mm male terminal, THT, 1x05 | 1 | Amazon | JST-XH 2.54mm kit | You can buy a kit on Amazon to cover all your needs for this project.
Male header | Male 2.54mm 1x06 | 1 | Amazon | Male and femal 2.54 headers kit | You can buy a kit on Amazon to cover all your needs for this project.
Male header | Male 2.54mm 1x05 | 1
Male header | Male 2.54mm 1x02 | 1
Resistor 1/4W | 27kOhms | 1 | Amazon | 27kOhms 1/4W resistor | You won't find those easily in a kit…
Ceramic capacitor | 0.1uF - 5mm between pins | 3 | Digikey | 0.1uF Ceramic Capacitor | Beware that some ceramic capacitors on Amazon or Aliexpress are fake or out of spec.
Capacitor | 10uF 10V 4mm dia x 7mm, 1.5mm between pins | 1 | Digikey, Mouser, Amazon | 10 uF 25V 4x7mm | 6.3V is the minimum for this capacitor.
Description | Dimensions / Value | Qté | Supplier | Part Number | Comments
Bar meter jumper connector | JST-XH254 5pins female-female 10-15 cm | 1 | Amazon, Aliexpress | JST-XH254 5pins female-female 10-15 cm | 10cm is a little short, 20 is a little long, 15cm rarely available unfortunatly
Potentiometer connector plug | Dupont female plug 1x03 | 2 | Amazon, Aliexpress | Dupont kit | You can try to build a kit from this link for your needs. You can take longuer pre-clamp wire and cut them in half to make 2 wires…
Switches and buttons connector plug | Dupont female plug 2x06 | 1
Wires for potentiometer, switches and buttons | Dupon female pre-clamp wire 20cm | 18
Leds Strip jumper connector | Female JST-XH254 3pins to wire jumper 20cm | 1 | Amazon, Aliexpress | JST-XH254 jumper | You can try to make your jumper out of a kit like that.
Speaker connector | Female JST-XH254 2pins to wire jumper 20cm | 1
Smoke vacuum pump connector | Female JST-XH254 2pins to wire jumper 20cm | 1
Smoke fan connector | Female JST-XH254 2pins to wire jumper 20cm | 1
Batterie connector | Female JST-XH254 2pins to wire jumper 20cm | 1

Bar Meter PCBs

Câbles and jumpers

Page 2

Description | Dimensions / Value | Qté | Supplier | Part Number | Comments
Toggle switche | Blue mini MTS-101 2-pin SPST | 4 | Amazon | Blue mini MTS-101 SPST | Could also be MTS-102 3pin SPDT
Push button with yellow led indicator | R16-503 16mm Momentary Push Button 4pin Yellow | 1 | Amazon, Digikey, Mouser | R16-503 16mm Momentary Push Button 4pin | Be carefull, choose Momentory and 4 pins…
Yellow
Link for refrence only

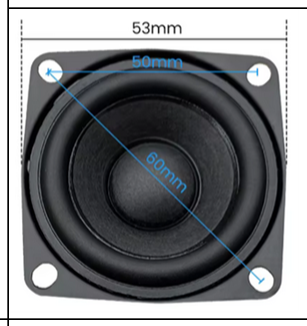
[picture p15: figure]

Potentiometer | B10K, 15mm shaft | 2 | Amazon | B10K 15mm shaft | For the hue control in the Clippard valve, potentiometer pins could have to be bent or cut to fit inside…
Mini vacuum pump (for smoke) | 5VDC, less then 500mA | 1 | Amazon, Aliexpress | No model number | IMPORTANT :This pump fits the Clippard valve BUT there is no success in using it with a vaccum self trigerred ecig. So smoke effects are still doable with the board outputs, but there is no good combinaison of pump and smoke device discovered yet. It's still a work in progress...

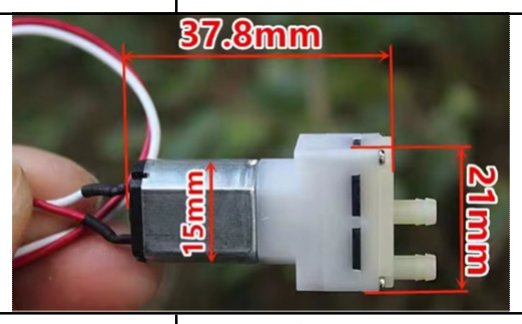
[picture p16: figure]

Fan (for smoke) | 3006 or 3007, 2pins, 5VDC, less then 500mA | 1 | Amazon | 3006 5v 2pin fan | 3006 are more expensive then 3007 fan…

Accesories

I do not recommand any speaker. Foot print must match this :

Must fit these dimensions to fit in the Clippard Valve.

Speaker | 2 inches 5W 4Ohms | 1 | Amazon, Aliexpress

Page 3

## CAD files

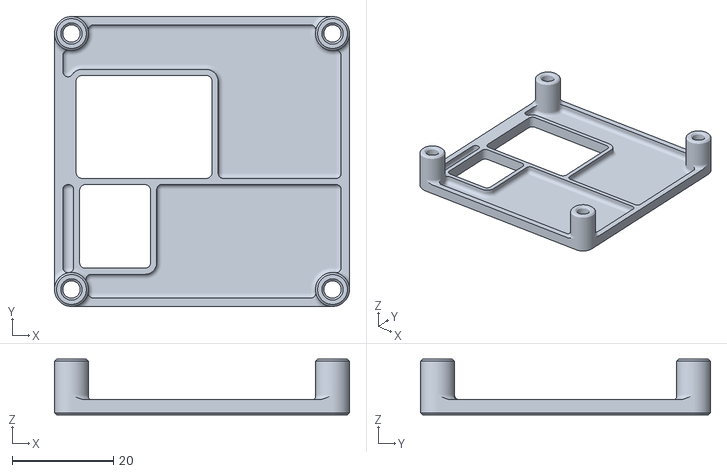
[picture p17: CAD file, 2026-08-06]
3D model/V2 - 20260806/32B Main PCB holder SBK PropCore One_OnePlus V2.stl
58.2 x 57.2 x 11.0

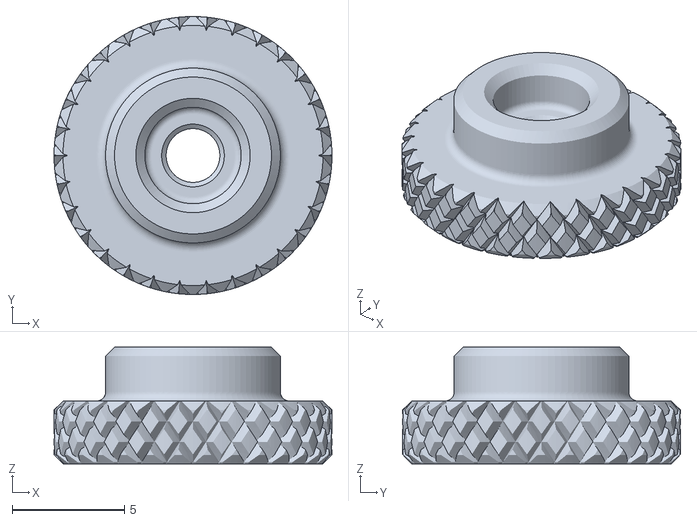
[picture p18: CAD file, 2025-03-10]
3D model/V2 - 20260806/15-Gunbox main side small knob.stl
12.4 x 12.4 x 5.20

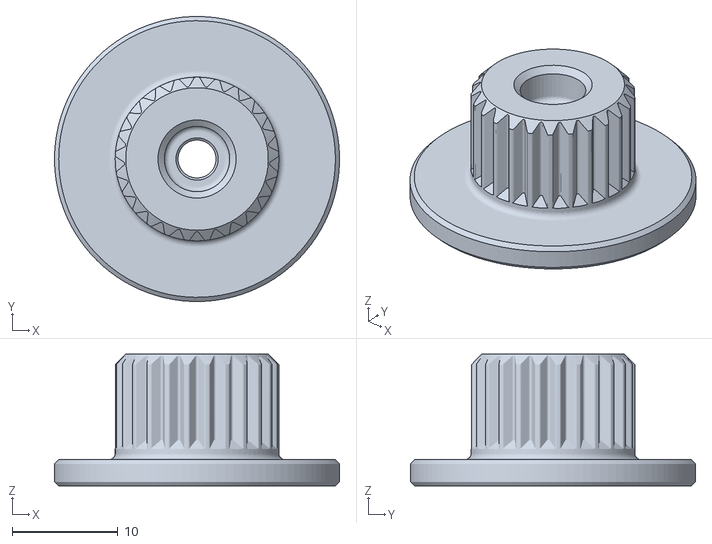
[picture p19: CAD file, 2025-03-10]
3D model/V2 - 20260806/14-Gunbox main side large knob.stl
27.0 x 27.0 x 12.5

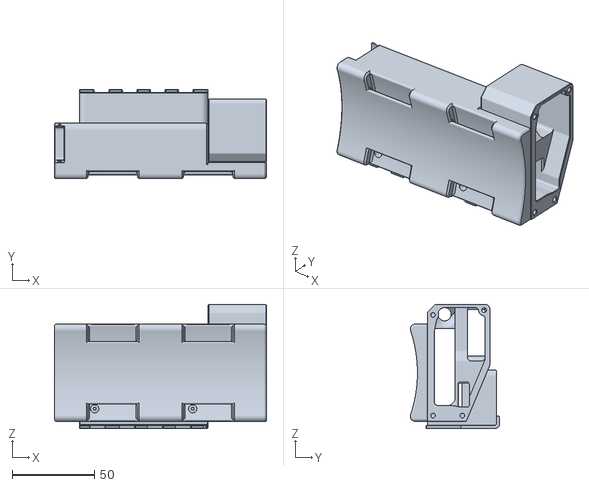
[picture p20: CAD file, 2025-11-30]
3D model/Battery pack holders/31.1C Battery pack holder and 24seg PowerCell v3.stl
128.7 x 54.3 x 75.4

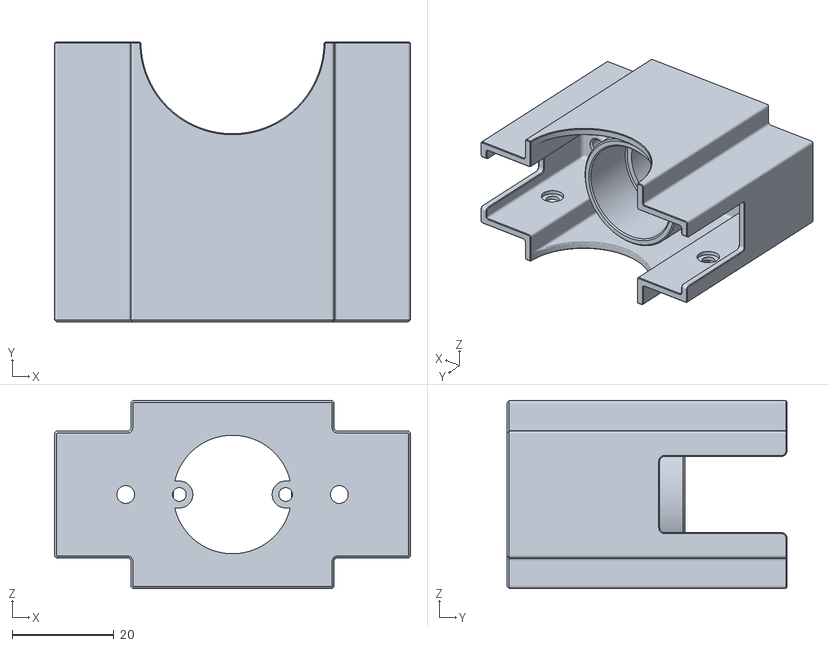
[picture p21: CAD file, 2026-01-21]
3D model/V1 - 20250310/01-Rod box.stl
70.0 x 55.0 x 37.0

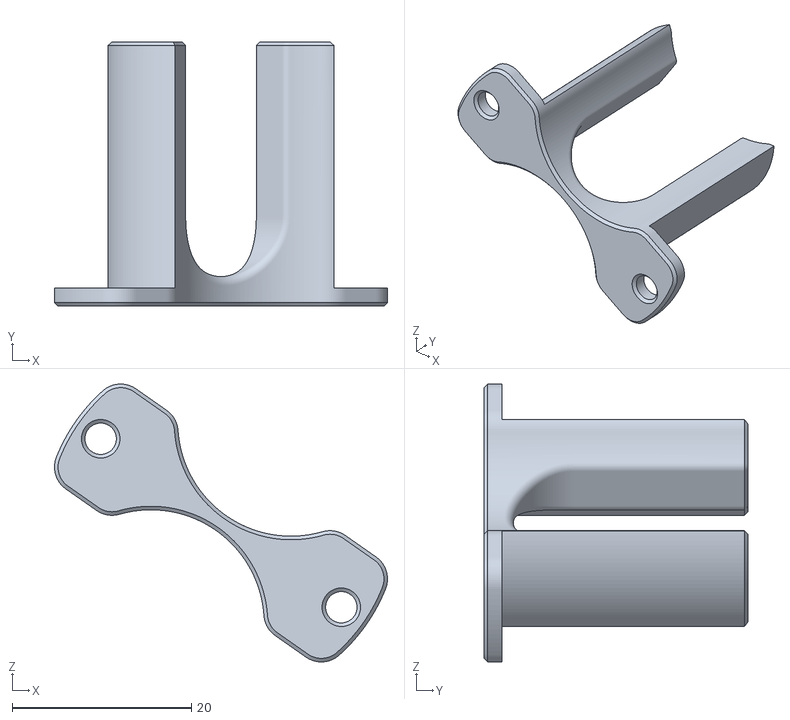
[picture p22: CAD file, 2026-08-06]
3D model/V2 - 20260806/34-Fire Rod LEDs Holder V2.stl
37.2 x 29.5 x 31.0

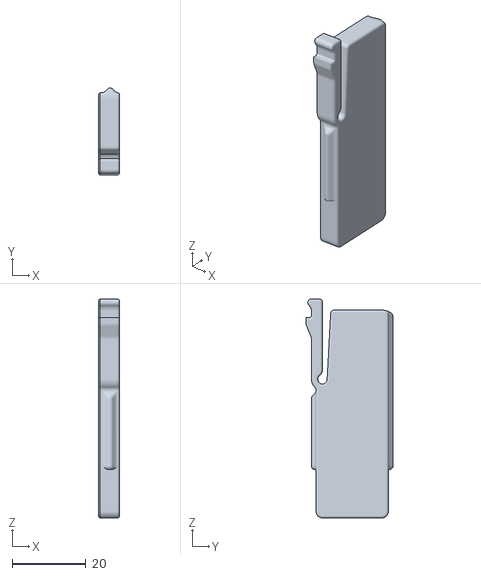
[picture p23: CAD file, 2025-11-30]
3D model/Battery pack holders/31.2C Battery pack holder COVER v3.stl
5.70 x 23.6 x 59.3

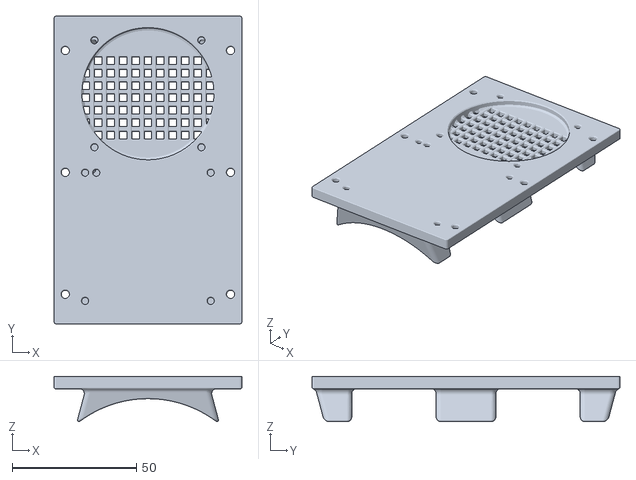
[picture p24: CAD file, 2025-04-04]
3D model/V1 - 20250310/03-Gunbox base plate C_D version.stl
75.6 x 123.8 x 18.2

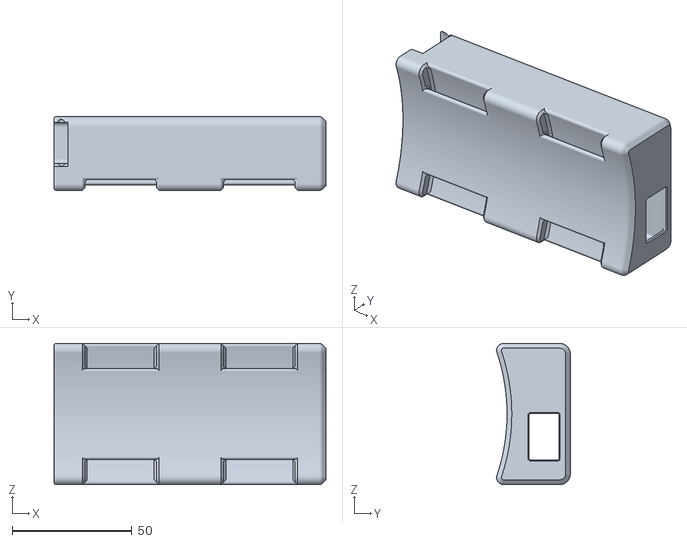
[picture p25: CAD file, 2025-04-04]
3D model/Battery pack holders/31.1A Battery pack holder with KCD1 switch.stl
113.7 x 30.8 x 59.0

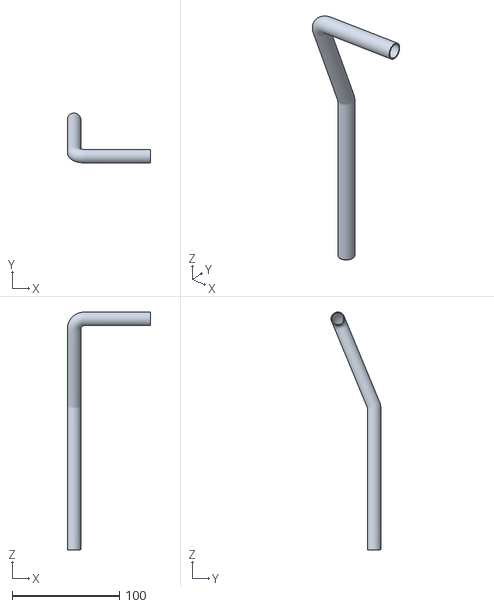
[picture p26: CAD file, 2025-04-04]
3D model/V1 - 20250310/33A Handle 3_8 copper tubing hollow (reference).stl
77.9 x 46.6 x 222.3

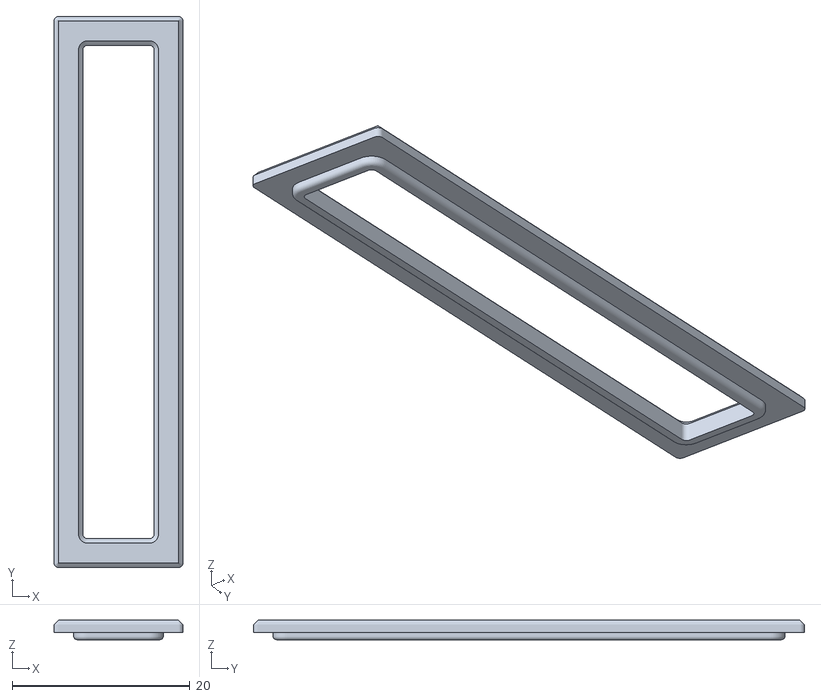
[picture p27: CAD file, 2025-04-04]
3D model/Battery pack holders/31.5B Powercell lens rim cover.stl
14.5 x 62.0 x 2.20

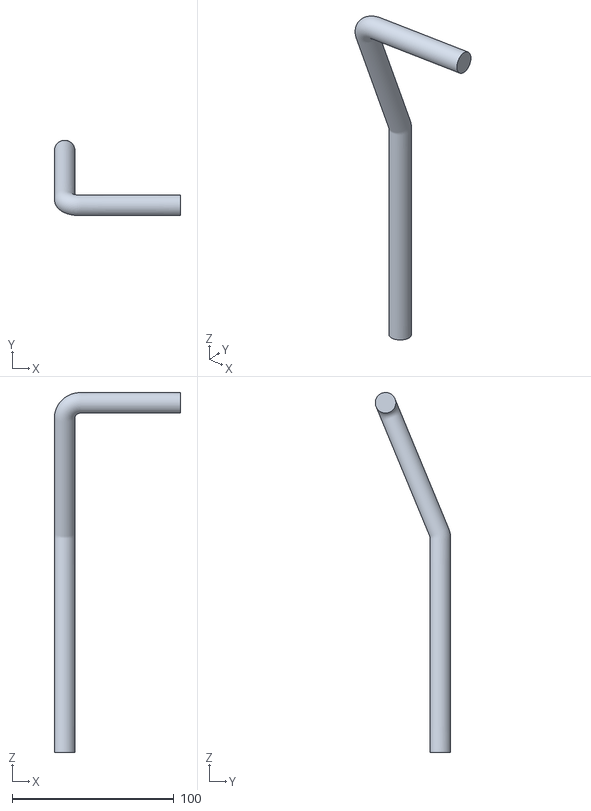
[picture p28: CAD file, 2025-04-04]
3D model/V1 - 20250310/33B Handle 3_8 copper tubing solid (reference).stl
77.9 x 46.6 x 222.3

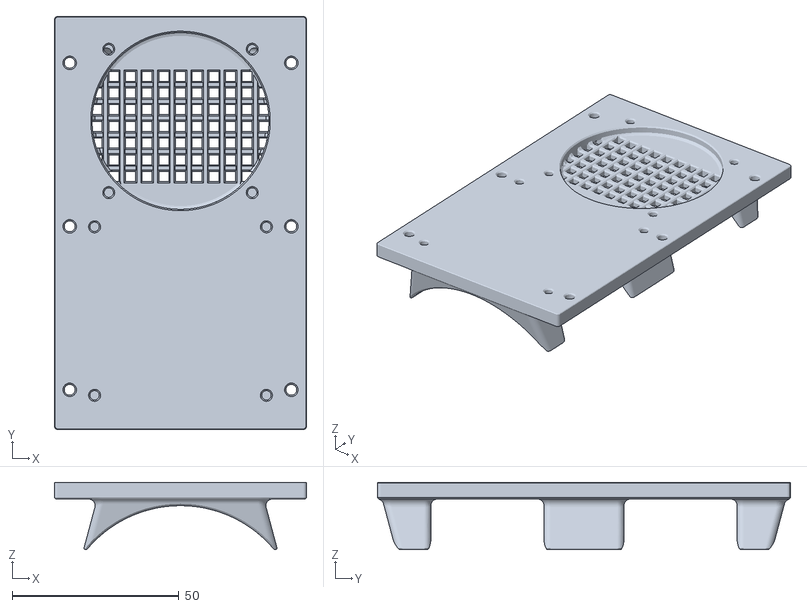
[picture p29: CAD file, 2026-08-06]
3D model/V2 - 20260806/03-Gunbox base plate for SMALL arm bracce V2.stl
75.6 x 123.8 x 20.2

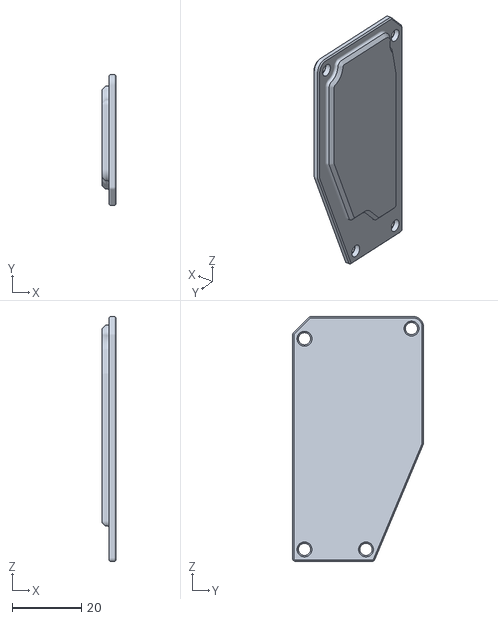
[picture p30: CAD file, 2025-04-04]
3D model/Battery pack holders/31.3C Powercell switch back cover.stl
4.00 x 38.0 x 71.0

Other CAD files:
3D model/V2 - 20260806/03-Gunbox base plate for Large arm bracce V2.stl
3D model/V1 - 20250310/02.3-Gunbox Bar graph support.stl
3D model/V2 - 20260806/17A-Clippart valve body.stl
3D model/Battery pack holders/31.2B Battery pack holder COVER.stl
3D model/Battery pack holders/31.2A Battery pack holder COVER.stl
3D model/Battery pack holders/31.3B Powercell switch back cover.stl
3D model/Battery pack holders/31.4B_C Cable gland.stl
3D model/Battery pack holders/31.6B Powercell 9x57x2mm lens (clear or frosted acrylic, not to be printed).stl
3D model/V1 - 20250310/02-Gunbox ONE PIECE.stl
3D model/V1 - 20250310/02.1-Gunbox.stl
3D model/V1 - 20250310/02.2-Gunbox top indicators leds support.stl
3D model/V1 - 20250310/02.4-Gunbox Front indicator led support.stl
3D model/V1 - 20250310/04-Arm brace D version.stl
3D model/V1 - 20250310/04-Arm brace D-trunk version.stl
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

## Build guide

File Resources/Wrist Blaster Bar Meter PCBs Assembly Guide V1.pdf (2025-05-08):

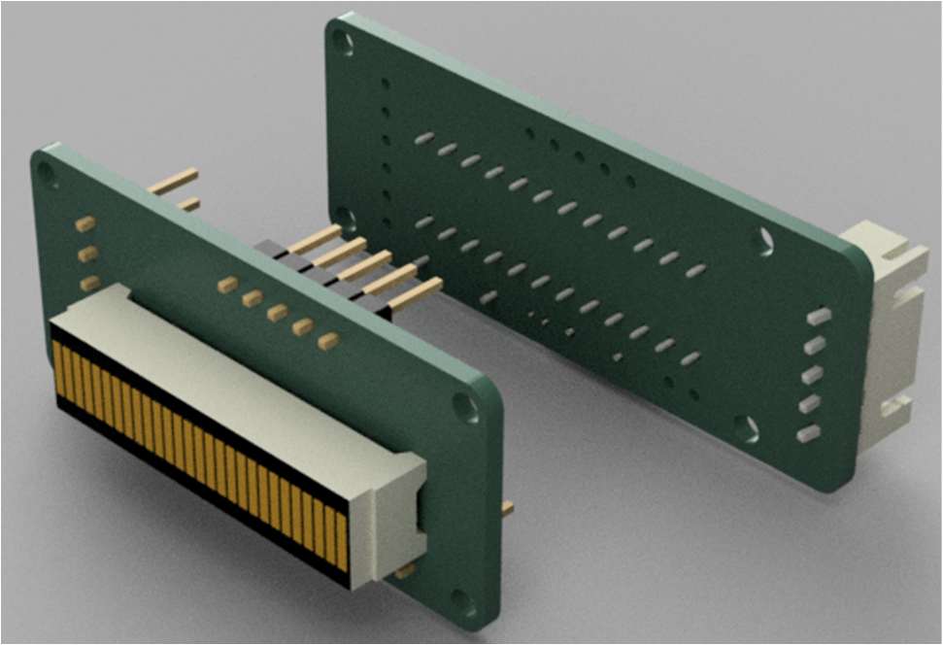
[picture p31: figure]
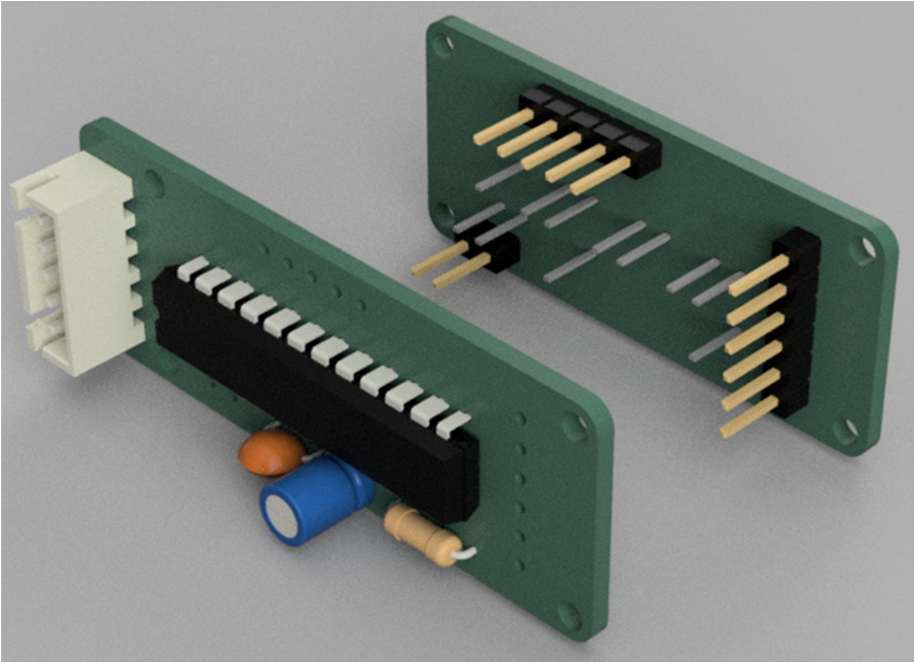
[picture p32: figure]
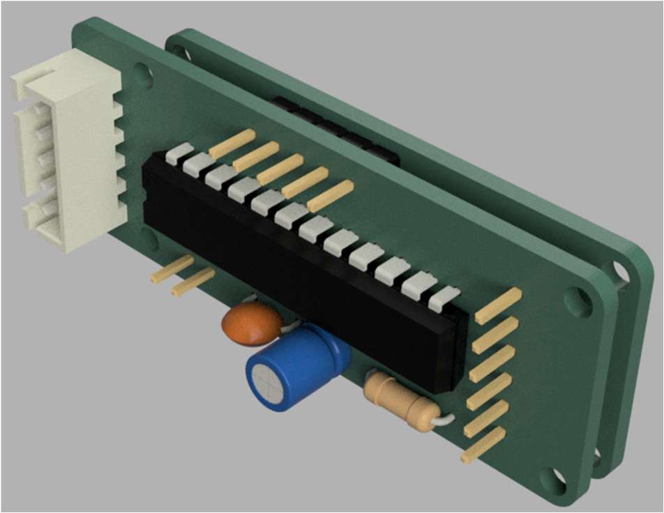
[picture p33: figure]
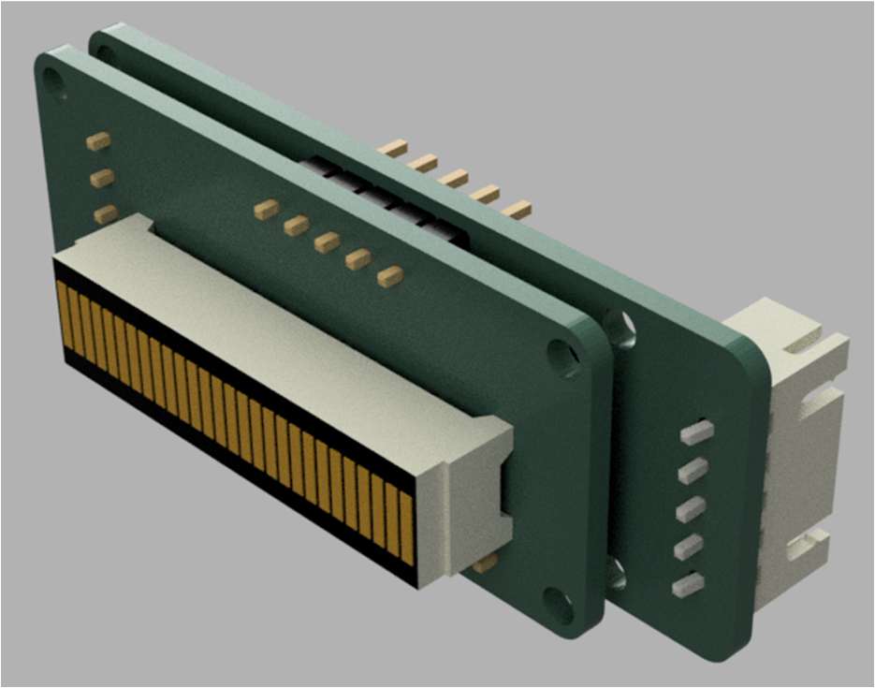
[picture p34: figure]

Page 1 / 2

Bar meter PCBs assembly Guide V0

Step 1 : Select the right bar meter driver PCB for your bar meter : common cathode SK or common anode SA. Check for SA or SK marking on the driver PCB and your bar meter.
Step 2 : Solder all components to both PCBs.
- Pins headers go on the bar meter PCB on the bar meter opposite side;
- Take time to place the MAX 72xx driver chip in the correct position, a white dot mark pin #1 on the PCB;
- Be careful with the electrolytic capacitor leads polarity, it must fits PCB marking + and -.
Step 3 : Trims the bar meter and driver pins close to PCBs so they don’t interfere with each other when PCBs are soldered in sandwich.
Step 4 : Solder both PCBs together with the pins headers.

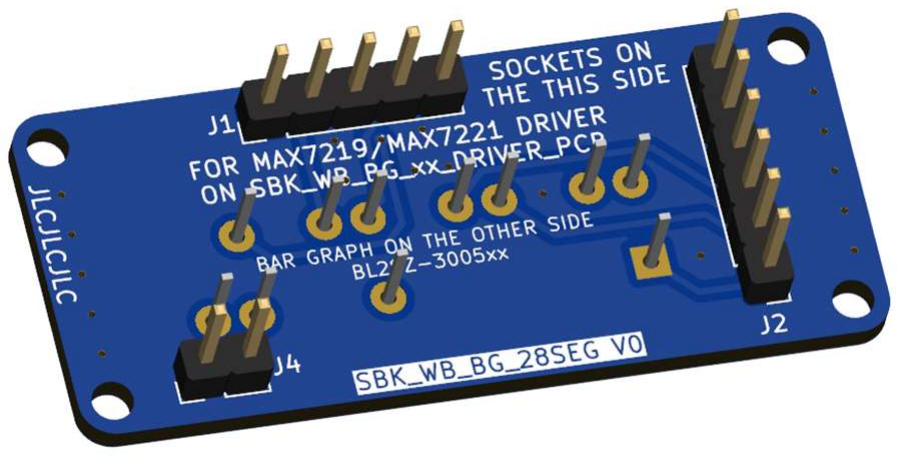
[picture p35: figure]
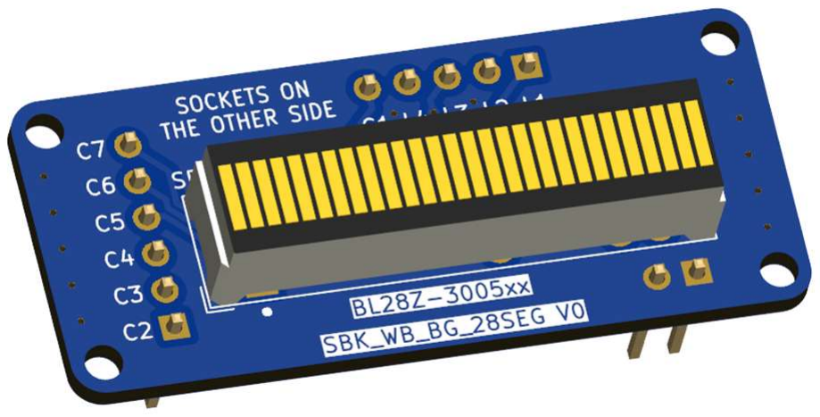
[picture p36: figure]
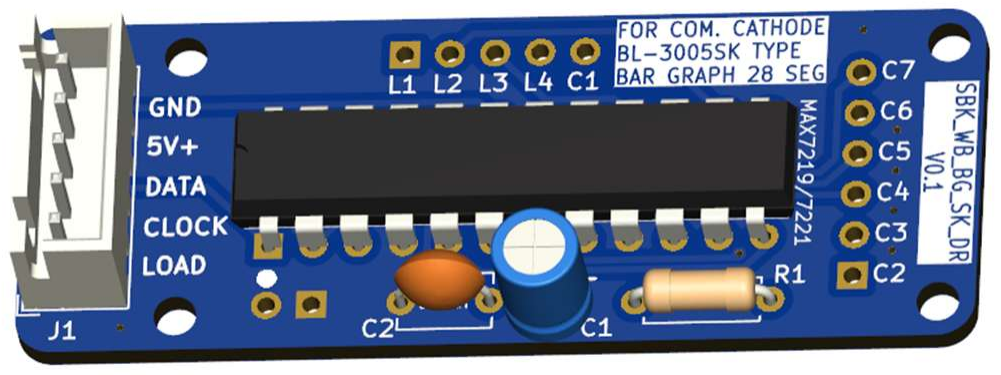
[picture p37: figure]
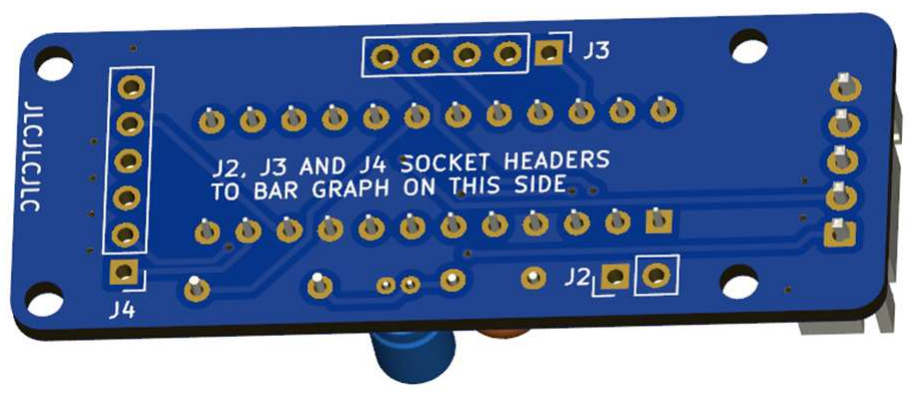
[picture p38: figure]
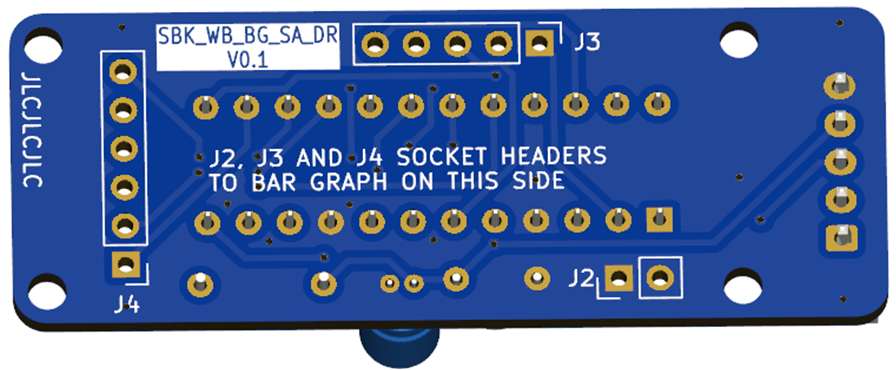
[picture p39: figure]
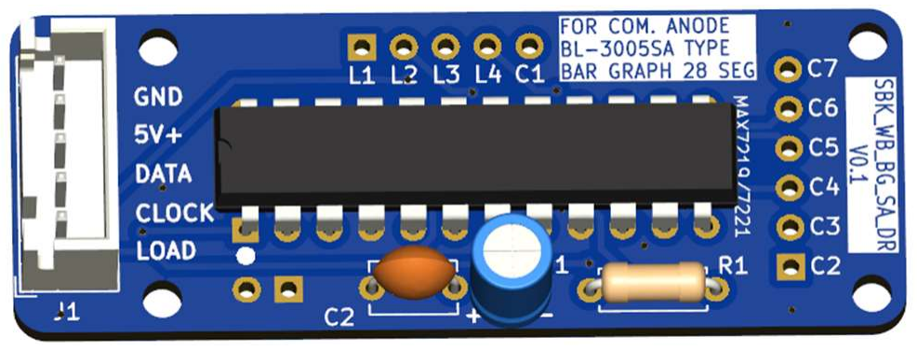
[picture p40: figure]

Page 2 / 2

Bar meter PCB :

SK bar meter driver PCB :

SA bar meter driver PCB :

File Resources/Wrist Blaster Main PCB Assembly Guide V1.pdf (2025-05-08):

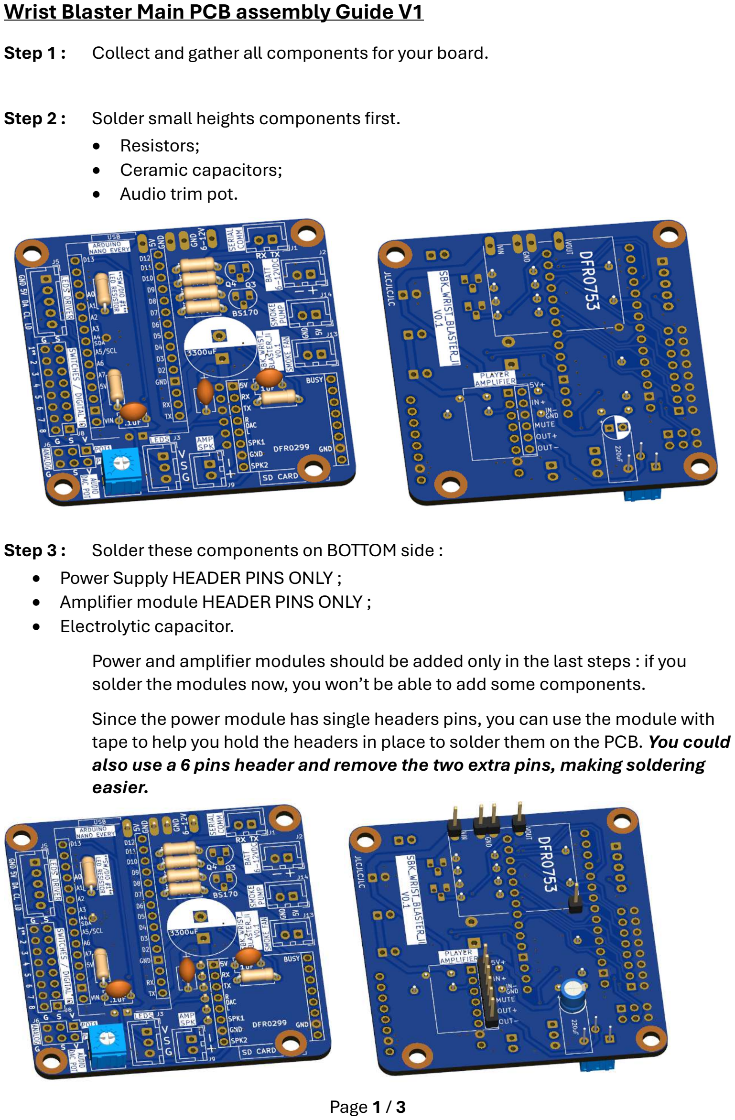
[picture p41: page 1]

Page 1 / 3

Wrist Blaster Main PCB assembly Guide V1

Step 1 : Collect and gather all components for your board.
Step 2 : Solder small heights components first.
- Resistors;
- Ceramic capacitors;
- Audio trim pot.
Step 3 : Solder these components on BOTTOM side :
- Power Supply HEADER PINS ONLY ;
- Amplifier module HEADER PINS ONLY ;
- Electrolytic capacitor.
Power and amplifier modules should be added only in the last steps : if you solder the modules now, you won’t be able to add some components.
Since the power module has single headers pins, you can use the module with tape to help you hold the headers in place to solder them on the PCB. You could also use a 6 pins header and remove the two extra pins, making soldering easier.

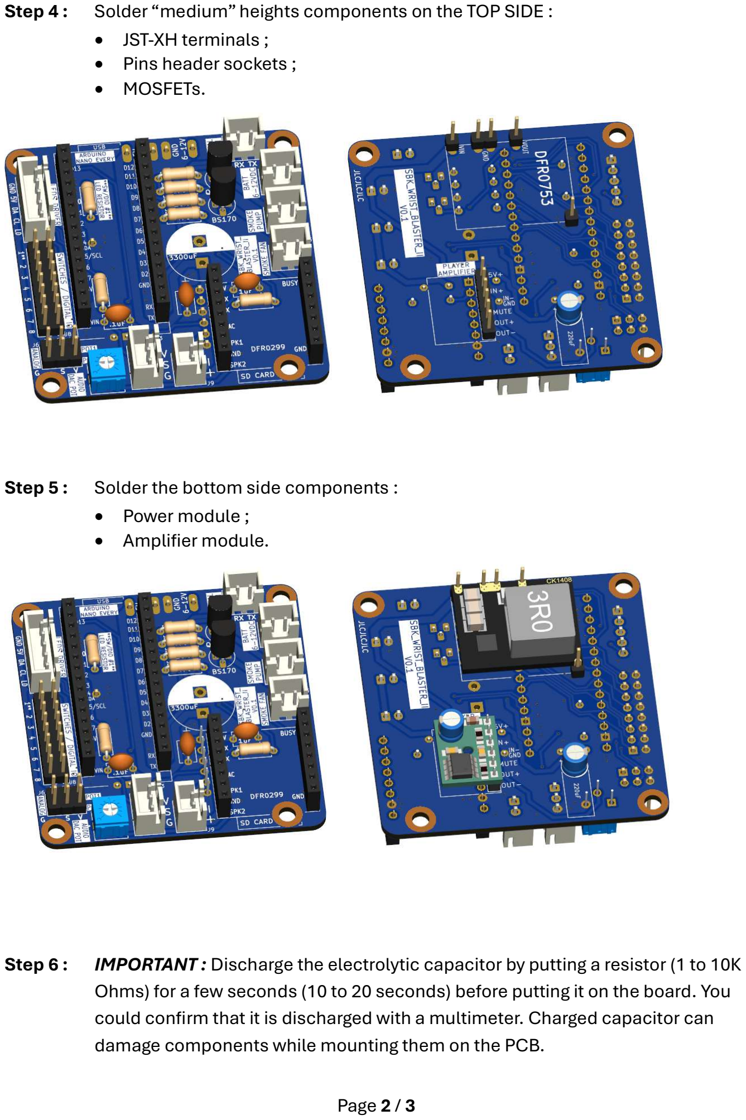
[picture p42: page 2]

Page 2 / 3

Step 4 : Solder “medium” heights components on the TOP SIDE :
- JST-XH terminals ;
- Pins header sockets ;
- MOSFETs.
Step 5 : Solder the bottom side components :
- Power module ;
- Amplifier module.
Step 6 : IMPORTANT : Discharge the electrolytic capacitor by putting a resistor (1 to 10K Ohms) for a few seconds (10 to 20 seconds) before putting it on the board. You could confirm that it is discharged with a multimeter. Charged capacitor can damage components while mounting them on the PCB.

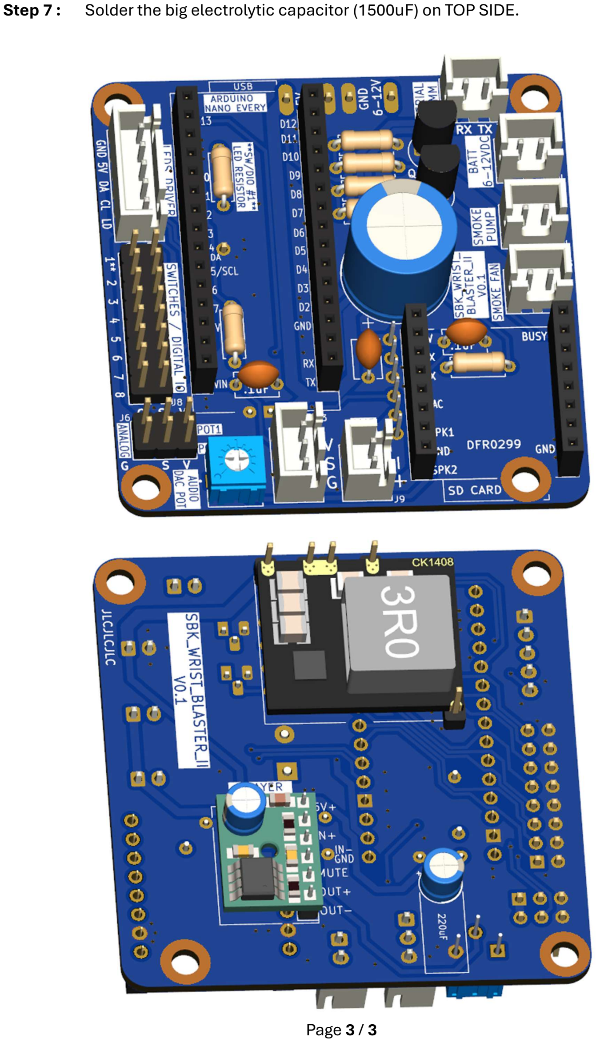
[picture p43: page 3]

Page 3 / 3

Step 7 : Solder the big electrolytic capacitor (1500uF) on TOP SIDE.

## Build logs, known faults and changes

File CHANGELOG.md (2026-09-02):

# Changelog

All notable firmware changes to the SBK Wrist Blaster project are documented in this file.

The format is based on [Keep a Changelog](https://keepachangelog.com/en/1.1.0/), and release versions follow [Semantic Versioning](https://semver.org/).

## 2.0.0 - 2026-09-02

### Added

- Reusable Cyclotron and Power Cell animation-scheme headers.
- Support for the external `SBK_Button`, `SBK_BarDrive`, `SBK_MAX72xx`, and `SBK_HT16K33` libraries.
- A lightweight bundled DFPlayer command engine, removing the need for `DFPlayerMini_Fast`.
- Arduino Nano Every and ATmega328-based Nano build support, subject to the selected features and available memory.

### Changed

- Reworked the main firmware state machine, configuration, and hardware pin definitions.
- Updated the battery-monitoring, Cyclotron, indicator, LED-strip base, player, Power Cell, firing-rod, smoke, and vent engines to version 2.0.0.
- Replaced the legacy bundled switch engine with `SBK_Button`.
- Replaced the legacy bundled bar-meter engines and drivers with the standalone SBK bar-meter libraries.
- Renamed the bundled engine directory to `SBK_WristBlaster_lib_V2_0_0`.
- Updated installation and dependency documentation for the 2.0 architecture.

### Removed

- Legacy `V1_1_0` switch, bar-meter, MAX72xx, and HT16K33 implementations from the active firmware bundle.
- The external `DFPlayerMini_Fast` dependency.

### Archived

- Preserved the complete 1.1.0 firmware release under `Previous firmware and sounds FX releases/V1_1_0`.

## 1.1.0 - 2026-08-27

### Added

- `STATE_ALL_ON_TO_OFF` for smoother sound and animation transitions.
- A configuration flag for enabling or disabling smoke-device support.
- Additional and revised sound tracks for the updated operating sequence.

### Changed

- Revised power-up, Cyclotron, firing, overheat, venting, and shutdown sequences.
- Improved smoke-device safety logic.
- Strengthened Cyclotron pixel-index validation.

### Fixed

- Several state-machine transitions.
- Firing-rod animation behavior.
- Additional minor firmware issues.

## 1.0.0

### Added

- Modular Wrist Blaster firmware with configurable controller pin definitions.
- DFPlayer Mini sound playback synchronized with prop states and animations.
- WS2812 effects for the firing rod, indicators, vent, Cyclotron, and optional Power Cell.
- MAX7219/MAX7221 and HT16K33 panel bar-meter support.
- Optional 24-segment bar-meter or WS2812 Power Cell.
- Optional battery-voltage monitoring and low-voltage shutdown.
- Configurable switches, buttons, potentiometers, animation directions, mappings, and serial debugging.

## 0.x

- Initial development firmware. Preserved under `Previous firmware and sounds FX releases/V0`.

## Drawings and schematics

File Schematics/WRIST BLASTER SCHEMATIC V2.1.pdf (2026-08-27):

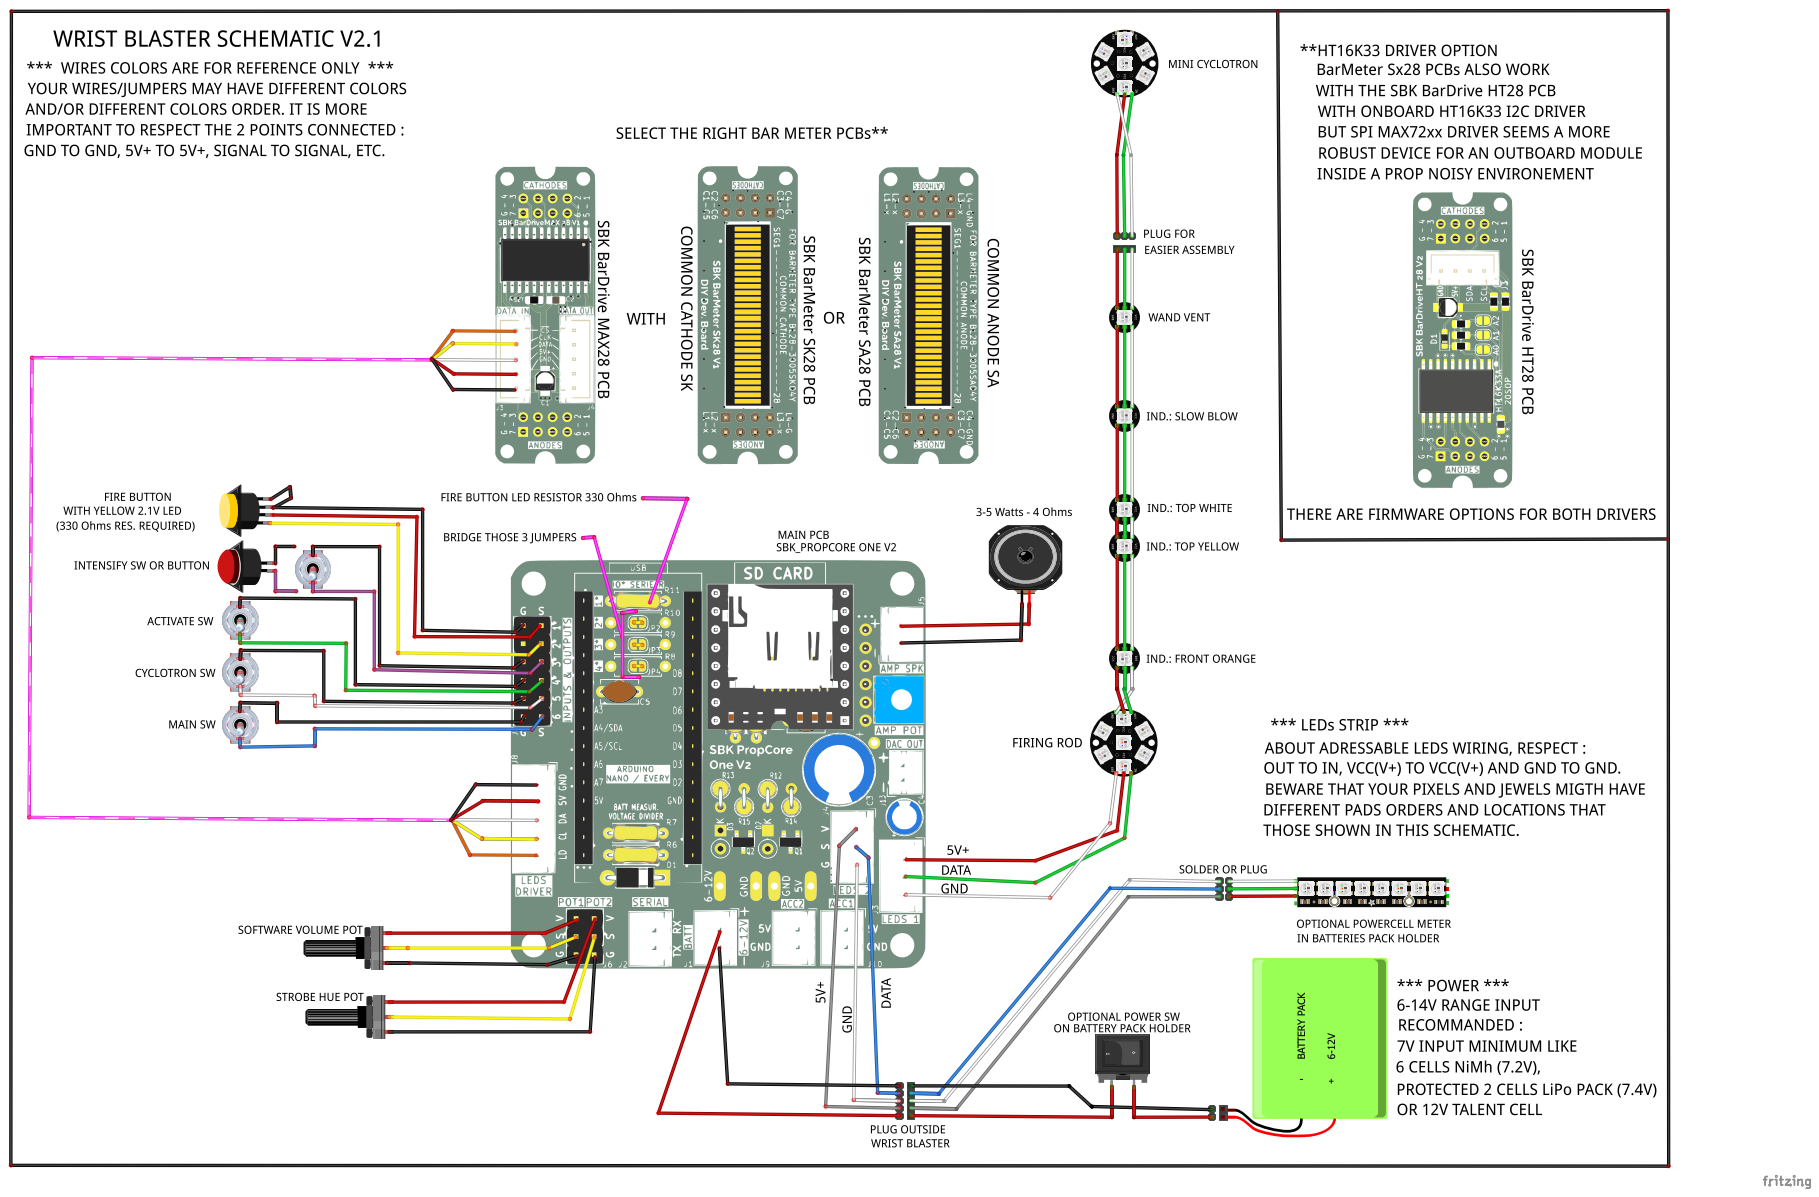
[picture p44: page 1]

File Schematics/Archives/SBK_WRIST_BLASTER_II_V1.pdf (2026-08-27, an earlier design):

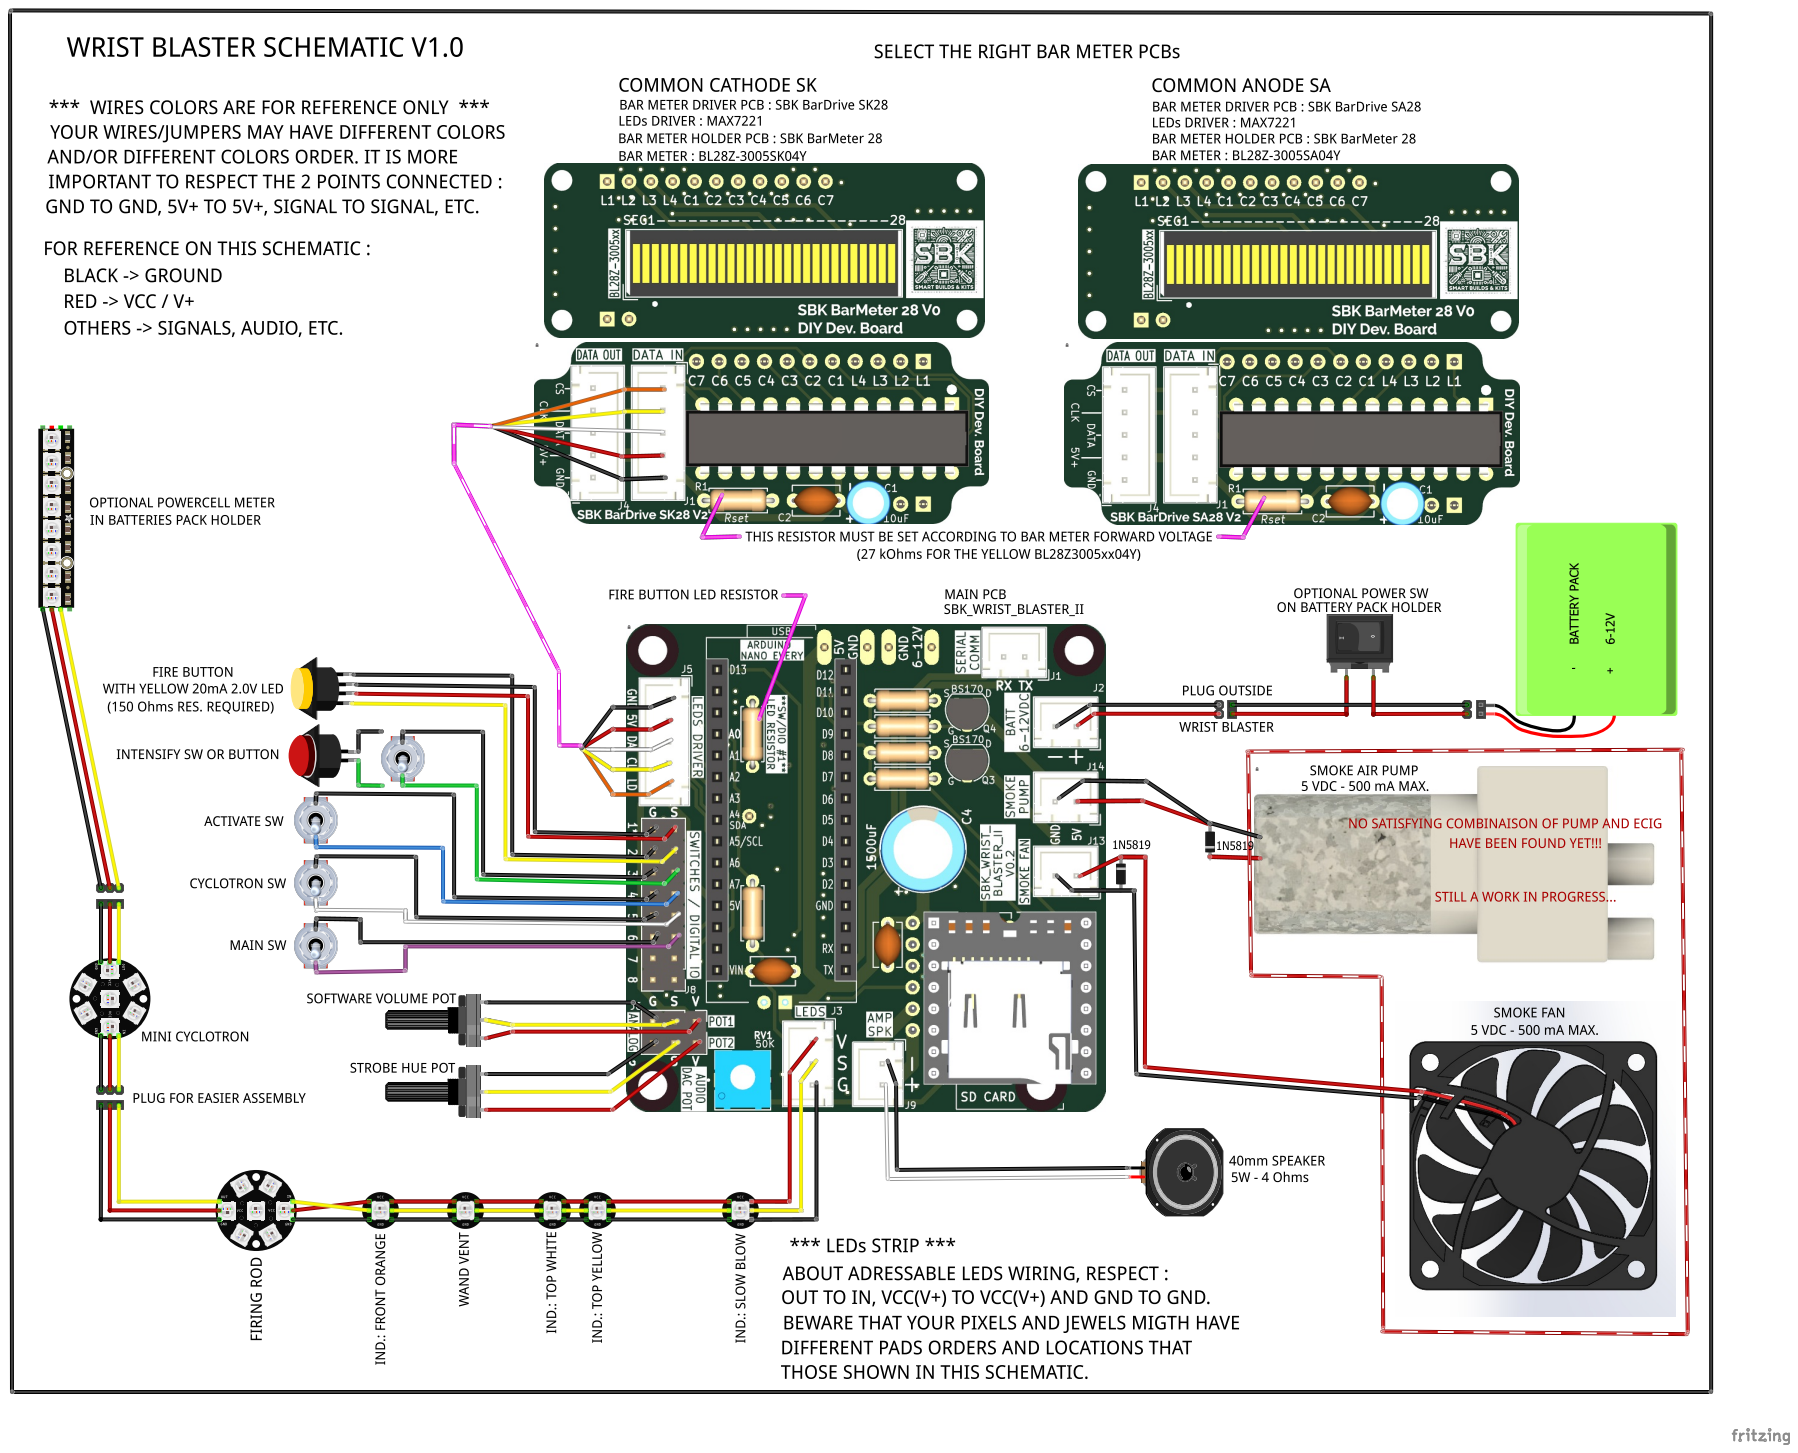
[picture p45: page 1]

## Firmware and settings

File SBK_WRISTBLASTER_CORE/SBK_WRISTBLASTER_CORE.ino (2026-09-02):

/**
 * @file        SBK_WRISTBLASTER_CORE.ino
 * @brief       Lights and sound control code for the SBK Wrist Blaster replica or other props.
 *
 * @author      Samuel Barabe
 * @copyright   Copyright (c) 2025-2026 Samuel Barabe
 * @license     MIT License
 * @version     2.0.0
 * @link        https://github.com/sbarabe/SBK_WRISTBLASTER
 *
 * @details
 * This software provides core functionality for animating lights and playing sound effects on
 * a wrist-mounted prop weapon. Designed with customization and extensibility in mind.
 *
 * Special thanks to @David Miyakawa for animations, sound effects, and workflow design.
 *
 * @see         https://opensource.org/licenses/MIT
 *
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
 * ---
 * CORE FILE NOTICE:
 * This file contains the main Wrist Blaster logic. Most users should configure the project through
 * SBK_WRISTBLASTER_CONFIG.h rather than modifying this file directly, unless you are an advanced
 * user intending to customize the workflow or animation effects.
 *
 * For general setup, use the SBK_WRISTBLASTER_CONFIG.h file to configure:
 * - Pin assignments
 * - LED indexes
 * - Track lengths
 * - Feature toggles
 *
 * Modify only the config file to match your specific hardware and desired behavior.
 * This keeps the core logic stable, clean, and easier to maintain.
 *
 * For setup instructions and documentation, visit:
 * https://github.com/sbarabe/SBK_WRISTBLASTER
 *
 * The core is modular and object-oriented, with components organized in the
 * `SBK_WristBlaster_lib` folder.
 *
 * Library dependencies:
 * - Adafruit NeoPixel
 * - SBK_Button
 * - SBK_BarDrive
 * - SBK_MAX72xx or SBK_HT16K33, depending on the selected bar-meter driver
 *
 * Audio control uses the built-in SBK_WB_PlayerEngine and requires no external
 * DFPlayer library.
 *
 * Supported features:
 * - DFPlayer Mini sound board
 * - LED bar meter (28 segments) via MAX72xx or HT16K33 drivers
 * - WS2812 LED animations (vent, cyclotron, indicators)
 * - Configurable buttons/switches for boot, fire, mode, and smoke
 * - Firing rod hue potentiometer input
 * - Party mode, burst fire mode, and smoke toggle
 *
 * Important Notes:
 * - Predefined track durations provide the timeline for state transitions,
 *   animations, and effects, as well as audio playback timing when the BUSY pin is not used.
 * - Incorrect durations may desynchronize animations and effects from the audio track.
 * - Advanced users may customize animations or state transitions in the core engine.
 *
 * If you find this useful, please consider supporting development at:
 * https://github.com/sbarabe/SBK_WRISTBLASTER
 *
 * @see https://opensource.org/licenses/MIT
 * DFPlayer Mini commands are sent by the lightweight SBK_WB_PlayerEngine.
 * @see https://github.com/adafruit/Adafruit_NeoPixel
 **/

#include <Arduino.h>
#include "SBK_WRISTBLASTER_CONFIG.h"

/*********************************************/
/*      GENERAL definitions and helpers      */
/*********************************************/
// Helpers variables declarations and initial states :
uint32_t now = 0;                            // To keep track in a loop
BlasterState WBstate = STATE_POWER_OFF;      // Initial wrist blaster state in the main loop
BlasterState prevState = STATE_ZERO;         // State tracking for some sequences
bool stateInitialized = false;               // False until the current state is initialized
bool prevStateInitialized = false;           // Previous value used by debug tracking
uint32_t stateStartTime = 0;                 // general time tracker for functions timers and delays
uint8_t heatLevel = 0;                       // Tracker for overheat
uint32_t heatLevelPrevUpdate = 0;            // Tracker for overheat
OverheatPhase overheatPhase = PHASE_WARNING; // Initial overheat phase
bool phaseInitialized = false;               // False until the current phase is initialized
uint32_t phaseStartTime = 0;                 // Shared phase start time tracker
BurstPhase burstPhase = BURST_PHASE_FIRING;
#ifndef CAPTURE
constexpr bool CAPTURE = false;
#endif
#ifndef BURST
constexpr bool BURST = true;
#endif
bool fireType = CAPTURE; // 0 = Capture, 1 = Burst : help managing reboots and firing tails
uint8_t battLevel = 100; // Battery level variable for battery power monitoring option
uint32_t prevBattReading = 0;
// Helpers functions declarations, functions are defined after the main loop :
bool stateInitialization();                                         // Standard initialisation sequence for most states
void handleWristBlasterState();                                     // Execute the primary state-machine control flow
bool checkIfTrackDoneExit(BlasterState next_state);                 // Change state when the current track timeline ends
bool checkIfSwitchExit(bool switch_state, BlasterState next_state); // Change state when the supplied switch condition is true
bool checkIfTimerExit(uint16_t time, BlasterState next_state);      // Change state when the current state timer expires
void enterState(BlasterState next_state);                           // Prepare phase data and enter a new state
void getLEDsSchemeForThisState();                                   // This function contains animations settings and calling for all states
void getIndicatorScheme();
void getSlowBlowIndicatorScheme();
void getTopWhiteIndicatorScheme();
void getTopYellowIndicatorScheme();
void getFrontOrangeIndicatorScheme();
void getFireButtonIndicatorScheme();
void getVentScheme();
void getPanelBarMeterScheme();
void getCyclotronScheme();
void getFiringRodScheme();
void getPowerCellScheme();                        // This function contains optional Power Cell animations
void playThisStateTrack();                        // play state track
void playThisTrack(uint8_t track);                // Play a specific track other than the state track
uint16_t getDuration();                           // Get the usable animation/effect duration of the current state
uint16_t getSpecificDuration(BlasterState state); // Get the usable animation/effect duration of a specific state
void checkNextPreviousButton();                   // While in party mode, switch to previous/next song with fire button
void heatLevelCooling();                          // Manage heat level
void heatLevelRisingBurst();                      // Manage heat level
void heatLevelRisingCapture();                    // Manage heat level
#ifdef SMOKE_FEATURES_ENABLED
void checkSmokerEnabling();
#endif                              // Check fire button operation to enable/disable smoke effect
uint8_t getCaptureScaledDuration(); // Scale Capture state duration to be compatible with heat level management
bool getPartyModeState();           // Helper to manage PBIntensify output as a switch or a push button

/*********************************************/
/*           BAR METER & DRIVER(s)           */
/*********************************************/
//  BAR METER with shift registers
//  Bar meter helper variables for 28 segments bar meter:
//  DRIVER type, animations DIRECTION and segments MAPPING should be defined in SBK_WRISTBLASTER_CONFIG.h file
#ifdef PBM_MAX72XX
#if defined(PCBM_MAX72XX_ON_PBM_CHAIN)
constexpr uint8_t PBM_MAX72XX_DEVICE_COUNT = 2;
#else
constexpr uint8_t PBM_MAX72XX_DEVICE_COUNT = 1;
#endif

SBK_MAX72xxSoft PBM_driver(PBM_DIN_PIN, PBM_CLK_PIN, PBM_LOAD_PIN, PBM_MAX72XX_DEVICE_COUNT);
#if defined(PBM_BL28_3005SK_MAPPING)
SBK_BarDrive<SBK_MAX72xxSoft> panelBarMeter(&PBM_driver, PBM_BARDRIVE_DEVICE_INDEX,
                                            MatrixPreset::BL28_3005SK,
                                            static_cast<BarDirection>(PBM_DIRECTION));
#else
SBK_BarDrive<SBK_MAX72xxSoft> panelBarMeter(&PBM_driver, PBM_BARDRIVE_DEVICE_INDEX,
                                            MatrixPreset::BL28_3005SA,
                                            static_cast<BarDirection>(PBM_DIRECTION));
#endif
#elif defined(PBM_HT16K33)
#if defined(PBM_BL28_3005SK_MAPPING)
SBK_HT16K33 PBM_driver(1);
SBK_BarDrive<SBK_HT16K33> panelBarMeter(&PBM_driver, PBM_BARDRIVE_DEVICE_INDEX,
                                        MatrixPreset::BL28_3005SK,
                                        static_cast<BarDirection>(PBM_DIRECTION));
#else
SBK_HT16K33 PBM_driver(1);
SBK_BarDrive<SBK_HT16K33> panelBarMeter(&PBM_driver, PBM_BARDRIVE_DEVICE_INDEX,
                                        MatrixPreset::BL28_3005SA,
                                        static_cast<BarDirection>(PBM_DIRECTION));
#endif
#endif

const uint8_t PANEL_MAX_PERCENT = 100;
uint8_t panelHeatFloorPercent = 0;

/***********************************************/
/*               WS2812 LEDs strip             */
/***********************************************/
// LEDs index, positions and animations directions should be defined in SBK_WRISTBLASTER_CONFIG.h file
// Define the main WS2812 LEDs strip for the wrist blaster. If the Power Cell LEDs are on the same strip,
// the total number of LEDs includes both the blaster and the Power Cell LEDs.
#if defined(POWERCELL_STRIP) && POWERCELL_ON_SAME_STRIP
Adafruit_NeoPixel blasterLeds = Adafruit_NeoPixel(TOTAL_LEDS_NUMBER + POWERCELL_NUMLEDS, LEDS_STRIP1_PIN, MAIN_STRIP_COLOR_ORDER + NEO_KHZ800);
#else
Adafruit_NeoPixel blasterLeds = Adafruit_NeoPixel(TOTAL_LEDS_NUMBER, LEDS_STRIP1_PIN, MAIN_STRIP_COLOR_ORDER + NEO_KHZ800);
#endif
FiringRod firingRod(&blasterLeds,
                    FIRE_ROD_POT_PIN, HUE_POT_READY,
                    ROD_NUMLEDS, LED_INDEX_TIP_1ST, LED_INDEX_TIP_LAST);
Vent vent(&blasterLeds, LED_INDEX_VENT);
Indicator slowBlowIndicator(&blasterLeds, LED_INDEX_SLOWBLOW);
Indicator topYellowIndicator(&blasterLeds, LED_INDEX_TOP_YELLOW);
Indicator topWhiteIndicator(&blasterLeds, LED_INDEX_TOP_WHITE);
Indicator frontOrangeIndicator(&blasterLeds, LED_INDEX_FRONT_ORANGE);
Cyclotron cyclotron(&blasterLeds,
                    CYC_NUMLEDS, LED_INDEX_CYC_START, LED_INDEX_CYC_END,
                    CYC_RING_1ST, CYC_RING_LAST, CYC_CENTER,
                    CYCLOTRON_DIRECTION);

/***********************************************************/
/*     POWER CELL LEDS STRIP OR BARMETER (OPTIONAL)        */
/***********************************************************/
#if defined(POWERCELL_STRIP) || defined(POWERCELL_BARMETER)
#define POWERCELL_EXIST
#endif
#if defined(POWERCELL_STRIP) && POWERCELL_ON_SAME_STRIP
PowerCell powerCell(&blasterLeds, POWERCELL_NUMLEDS, POWERCELL_FIRST, POWERCELL_LAST, POWERCELL_DIRECTION);
#elif defined(POWERCELL_STRIP) && defined(LEDS_STRIP2_PIN)
Adafruit_NeoPixel powercellLeds = Adafruit_NeoPixel(POWERCELL_NUMLEDS, LEDS_STRIP2_PIN, POWERCELL_STRIP_COLOR_ORDER + NEO_KHZ800);
PowerCell powerCell(&powercellLeds, POWERCELL_NUMLEDS, POWERCELL_FIRST, POWERCELL_LAST, POWERCELL_DIRECTION);
#elif defined(POWERCELL_STRIP) && !defined(LEDS_STRIP2_PIN)
#error "Power Cell LEDs STRIP : Optional NEW Power Cell LEDs strip enabled but strip pin is not defined, wrong board or wrong pins definition."
#endif
#if defined(POWERCELL_BARMETER) && defined(PCBM_MAX72XX_ON_PBM_CHAIN)

// No new driver instance: use device 1 of PBM_driver.
SBK_BarDrive<SBK_MAX72xxSoft> powerCellBarMeter(
    &PBM_driver, PCBM_BARDRIVE_DEVICE_INDEX,
    PCBM_BARDRIVE_ROWS, PCBM_BARDRIVE_COLUMNS,
    POWERCELL_DIRECTION ? BarDirection::REVERSE : BarDirection::FORWARD);

#elif defined(POWERCELL_BARMETER) && defined(PCBM_MAX72XX_SEPARATE)

#if (defined(PCBM_DIN_PIN) + defined(PCBM_CLK_PIN) + defined(PCBM_LOAD_PIN)) != 3
#error "POWER CELL BAR METER : bar meter with MAX72xx deriver is defined but the pins are undefined (PCBM_DIN_PIN, PCBM_CLK_PIN, PCBM_LOAD_PIN). Wrong board or wrong pins definition."
#endif
SBK_MAX72xxSoft PCBM_driver(PCBM_DIN_PIN, PCBM_CLK_PIN, PCBM_LOAD_PIN, 1);
SBK_BarDrive<SBK_MAX72xxSoft> powerCellBarMeter(
    &PCBM_driver, PCBM_BARDRIVE_DEVICE_INDEX,
    PCBM_BARDRIVE_ROWS, PCBM_BARDRIVE_COLUMNS,
    POWERCELL_DIRECTION ? BarDirection::REVERSE : BarDirection::FORWARD);
#elif defined(POWERCELL_BARMETER) && defined(PCBM_HT16K33)
SBK_HT16K33 PCBM_driver(1);
SBK_BarDrive<SBK_HT16K33> powerCellBarMeter(
    &PCBM_driver, PCBM_BARDRIVE_DEVICE_INDEX,
    PCBM_BARDRIVE_ROWS, PCBM_BARDRIVE_COLUMNS,
    POWERCELL_DIRECTION ? BarDirection::REVERSE : BarDirection::FORWARD);
#endif

#ifdef POWERCELL_BARMETER
uint8_t powerCellBatteryPercent = 100;
uint16_t powerCellAnimationInterval = PC_POWER_ON_UPDATE_INT / 2;
uint16_t powerCellRampStartInterval = PC_POWER_ON_UPDATE_INT / 2;
uint16_t powerCellRampTargetInterval = PC_POWER_ON_UPDATE_INT / 2;
uint16_t powerCellRampDuration = 0;
uint32_t powerCellRampStartTime = 0;
#endif

/***********************************************************/
/*           BATT POWER MEASUREMENT (OPTIONAL)             */
/***********************************************************/
#ifndef BATT_PIN
#pragma message("SBK_WRISTBLASTER_CORE : BATT_PIN not defined, no battery monitoring available.")
BattMoniroting batt; // No parameters = no batt monitoring
#else
BattMoniroting batt(BATT_PIN, POWER_MONITORING, selectedBattery, BATT_LOW_CUTOFF, BATT_READING_SCALING_FACTOR);
#endif

/***********************************************/
/*      Fire button Single Led Indicator       */
/***********************************************/
// This is not an addressable LED, it's a single led drive directly from the pin and a series resistor
// See CONFIG.H to enable/disable this indicator
SingleColorIndicator fireButtonSingleLed(FIRE_BUTTON_LED_PIN, FIRE_BUTTON_LED_READY);

/*********************************************/
/*    AUDIO PLAYER definition and helpers    */
/*********************************************/
/****************************/
/*    PLAYER definitions    */
/****************************/
Player player(VOLUME_MAX, VOLUME_START,
              RX_PIN, TX_PIN, BUSY_PIN,
              AMP_MUTE_PIN,
              VOL_POT_PIN, VOL_POT_READY,
              PLAYER_COMMAND_DELAY
#ifndef PLAYER_USE_BUSY_PIN
              ,
              AUDIO_ADVANCE
#endif
);
/************************************/
/* Audio board SERIAL COMMUNICATION */
/************************************/
#if defined(PLAYER_SOFTSERIAL) && !defined(DISABLE_AUDIO_PLAYER)
#include <SoftwareSerial.h>
SoftwareSerial SoftSerial(RX_PIN, TX_PIN);
#pragma message("Compiling for DFPlayer with SoftSerial communication.")
#elif defined(PLAYER_SERIAL1) && !defined(DISABLE_AUDIO_PLAYER)
#pragma message("Compiling for DFPlayer with Serial1 communication.")
#elif defined(DISABLE_AUDIO_PLAYER)
#pragma message("Compiling with audio player disabled (animation timing stub enabled).")
#endif
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
void loop()
{

  // Report state and initialization changes for troubleshooting.
#ifdef DEBUG_TO_SERIAL
  {
    if (WBstate != prevState || stateInitialized != prevStateInitialized)
    {
      DEBUG_PRINT("Wrist Blaster State = ");
      DEBUG_PRINT(WBstate);
      DEBUG_PRINT("  Initialized = ");
      DEBUG_PRINTLN(stateInitialized);

    }
  }
#endif

  // Get time for this loop
  now = millis();

  // Capture the previous state and initialization value for comparison in the next loop.
  if (WBstate != prevState)
      {
        prevState = WBstate;
      }
      if (stateInitialized != prevStateInitialized)
      {
        prevStateInitialized = stateInitialized;
      }

  // Check battery state and goes into POWER_DOWN then LOW_BATT if too low...
  if (now - prevBattReading > 2000)
  {
    prevBattReading = now;

    batt.updateReading();
    battLevel = batt.readBattPercentage();
    if (POWER_MONITORING &&
        WBstate != STATE_POWER_ON_TO_OFF &&
        WBstate != STATE_LOW_BATT &&
        batt.isBattTooLow())
    {
      enterState(STATE_POWER_ON_TO_OFF);
    }
  }

  // LEDS UPDATE
  bool update_leds_chain = false;
  getLEDsSchemeForThisState(); // Get new leds schemes for this loop
  // Update simple LEDs states to last animations schemes.
  panelBarMeter.animations().update(now);
  panelBarMeter.show();
  fireButtonSingleLed.update(now);
  // Optional Power Cell LEDs/BARMETER
// Update optional PowerCell addressable LEDs chain with last color schemes.
#ifdef POWERCELL_EXIST
  getPowerCellScheme();
#if defined(POWERCELL_STRIP) && !POWERCELL_ON_SAME_STRIP
  if (powerCell.update(now, battLevel))
    powercellLeds.show();
#elif defined(POWERCELL_STRIP) && POWERCELL_ON_SAME_STRIP
  {
    update_leds_chain |= powerCell.update(now, battLevel);
  }
#elif defined(POWERCELL_BARMETER)
  powerCellBarMeter.animations().update(now);
#if defined(PCBM_MAX72XX_ON_PBM_CHAIN)
  PBM_driver.show(PCBM_BARDRIVE_DEVICE_INDEX);
#else
  PCBM_driver.show(PCBM_BARDRIVE_DEVICE_INDEX);
#endif
#endif
#endif

  // Update addressable LEDs chain with last color schemes.
  update_leds_chain |= slowBlowIndicator.update(now);
  update_leds_chain |= topWhiteIndicator.update(now);
  update_leds_chain |= topYellowIndicator.update(now);
  update_leds_chain |= frontOrangeIndicator.update(now);
  update_leds_chain |= cyclotron.update(now);
  update_leds_chain |= vent.update(now);
  update_leds_chain |= firingRod.update(now);
  if (update_leds_chain) // Update only if required
    blasterLeds.show();

  // Check buttons and switches readings and states
  PBintensify.update(now);
  SWmain.update(now);
  SWcyclotron.update(now);
  SWactivate.update(now);
  PBfire.update(now);

#ifdef SMOKE_FEATURES_ENABLED
  // Update smoker
  smoker.update(now);
#endif

  // DFPlayer Mini Management
  player.update(now);
  player.setVolWithPot(); // Set audio volume with potentiometer

  // Keep updating engines above, but wait for the DFPlayer command interval
  // before sending another audio command or processing state transitions.
  if (!player.checkCommandDelay())
    return;

  // The player is ready: process the current state's runtime logic.
  handleWristBlasterState();
}
/********************** END_SEQ MAIN LOOP *******************/

///////////////////////////////////////////////////////////////
// Execute the control flow for the current blaster state.
// Phases inside a state coordinate animation and effect transitions.
///////////////////////////////////////////////////////////////
void handleWristBlasterState()
{
  switch (WBstate)
  {

  default:
  case STATE_ZERO:
  {
    DEBUG_PRINTLN("Invalid WBstate... Recovering to POWER-OFF state");
    DEBUG_PRINTLN();
    player.stop();
    enterState(STATE_POWER_OFF);
    break;
  }

  //////////////////////////////////////////////
  case STATE_LOW_BATT:
  {
    if (!stateInitialized) // Initiate this wrist blaster State :
    {
      DEBUG_PRINTLN("STATE_LOW_BATT");

      // Specifics state initializers :
      heatLevel = 0; // Reset heat level to 0
      player.stop(); // Stop player, no track for this state
      DEBUG_PRINTLN("Player STOP");
      DEBUG_PRINTLN();

      // Standard initializers
      stateStartTime = now;
      stateInitialized = true; // End state initialization when stateInitialized is 1
      // Wait for the DFPlayer command delay before running this state.
      break;
    }

    // Leave LOW_BATT once the pack voltage has recovered. If cutoff is
    // disabled, isBattTooLow() is false and this state exits safely too.
    if (!batt.isBattTooLow())
    {
      enterState(STATE_POWER_OFF);
      break;
    }
    break;
  }

  //////////////////////////////////////////////
  case STATE_PARTY_MODE:
  {
    if (!stateInitialized) // Initiate this wrist blaster State :
    {
      DEBUG_PRINTLN("STATE_PARTY_MODE");

      // Specifics state initializers :
      player.setThemesPlaymode(); // Play files in folder 01 on SD Card
      DEBUG_PRINTLN("Play FOLDER");
      DEBUG_PRINTLN();

      // Standard initializers
      stateStartTime = now;
      stateInitialized = true; // End state initialization when stateInitialized is 1
      // Wait for the DFPlayer command delay before running this state.
      break;
    }

    // Check Fire button to play next/previous themes track, needs a press and release
    checkNextPreviousButton();

    // Wrist blaster state exits by priority : check if wrist blaster goes into PARTY_MODE_OUT
    if (checkIfSwitchExit(!getPartyModeState(), STATE_PARTY_MODE_OUT))
      break;

    break;
  }

  //////////////////////////////////////////////
  case STATE_PARTY_MODE_IN:
  {
    if (!stateInitialized) // Initiate this wrist blaster State :
    {
      DEBUG_PRINTLN("STATE_PARTY_MODE_IN");
      DEBUG_PRINTLN();

      // Standard initializers
      stateInitialized = stateInitialization(); // End state initialization when stateInitialized is 1
      // Wait for the DFPlayer command delay before running this state.
      break;
    }

    // Wrist blaster state exits by priority :
    if (checkIfTrackDoneExit(STATE_PARTY_MODE)) // Check if track is ended before going into STATE_PARTY_MODE
      break;
    break;
  }

  //////////////////////////////////////////////
  case STATE_PARTY_MODE_OUT:
  {
    if (!stateInitialized) // Initiate this wrist blaster State :
    {
      DEBUG_PRINTLN("STATE_PARTY_MODE_OUT");
      DEBUG_PRINTLN();

      // Standard initializers
      stateInitialized = stateInitialization(); // End state initialization when stateInitialized is 1

      // Wait for the DFPlayer command delay before running this state.
      break;
    }

    // Wrist blaster state exits by priority :

    // Determine next state :
    BlasterState next = WBstate;
    if (SWmain.isReleased())
      next = STATE_POWER_OFF;
    else if (SWcyclotron.isReleased())
      next = STATE_POWER_OFF_TO_ON;
    else
      next = SWactivate.isPressed() ? STATE_CYCLOTRON_ON_TO_FULL : STATE_CYCLOTRON_OFF_TO_ON;

    // If track's done, go to next state
    if (checkIfTrackDoneExit(next))
      break;
    break;
  }

  //////////////////////////////////////////////
  case STATE_POWER_OFF:
  {
    if (!stateInitialized) // Initiate this wrist blaster State :
    {
      DEBUG_PRINTLN("STATE_POWER_OFF");
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

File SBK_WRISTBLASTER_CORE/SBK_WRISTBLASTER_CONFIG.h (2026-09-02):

/**
 * @file        SBK_WRISTBLASTER_CONFIG.h
 * @brief       Configuration file for the SBK_WRISTBLASTER_CORE system.
 *
 * @author      Samuel Barabé
 * @copyright   Copyright (c) 2025-2026 Samuel Barabé
 * @license     MIT License
 * @version     2.0.0
 * @link        https://github.com/sbarabe/SBK_WRISTBLASTER
 *
 * @details
 * This file contains all user-adjustable settings for the SBK Wrist Blaster system.
 *
 * It includes:
 * - Pin assignments (per board type)
 * - LED indexes
 * - Track durations
 * - Feature toggles
 *
 * Modify this file to match your specific hardware configuration and desired behaviors.
 *
 * For full setup instructions and documentation, and to support this project, please visit:
 * https://github.com/sbarabe/SBK_WRISTBLASTER
 *
 *
 * @see https://opensource.org/licenses/MIT
 * DFPlayer Mini commands are sent by the lightweight SBK_WB_PlayerEngine.
 * @see https://github.com/adafruit/Adafruit_NeoPixel
 */

/**********************************************************************************************
 *
 *  SBK_WRISTBLASTER CONFIGURATION FILE
 *
 *  - All your hardware and functional settings should be defined here.
 *  - Do NOT modify the core file (SBK_WRISTBLASTER_CORE.ino) unless you are an advanced user.
 *  - Avoid editing PINS_DEF unless you are defining a custom pin mapping.
 *  - This modular approach keeps the code clean, maintainable, and easy to update.
 *
 *  The codebase is modular and object-oriented, with the engine components located in the
 *  `SBK_WristBlaster_lib` folder.
 *
 * Important:
 * - Track durations define the timeline for state transitions, animations, and effects.
 *   When the BUSY pin is not used, they also determine audio playback completion.
 * - Incorrect durations may desynchronize animations and effects from the audio track.
 * - Advanced users may modify animations or state transitions in the core engine logic.
 *
 *  HOW TO USE THIS FILE:
 *  - Edit values only in blocks marked "USER SETTINGS".
 *  - For "Select ONE" choices, uncomment one #define and comment out the others.
 *  - Leave blocks marked "INTERNAL SETUP / VALIDATION" unchanged.
 *
 *  TIP: Save a backup of this file after customization.
 *
 ***********************************************************************************************/

#pragma once

#include <Arduino.h>

/******************************************************************************
 * DEBUG TO SERIAL
 ******************************************************************************/

// --- USER SETTINGS ----------------------------------------------------------
// Uncomment to send state and initialization diagnostics to the Serial monitor.
// #define DEBUG_TO_SERIAL

// --- INTERNAL SETUP / VALIDATION --------------------------------------------
#ifdef DEBUG_TO_SERIAL
#define DEBUG_PRINTLN(x) Serial.println(x)
#define DEBUG_PRINT(x) Serial.print(x)
#else
#define DEBUG_PRINTLN(x)
#define DEBUG_PRINT(x)
#endif
#ifdef ARDUINO_AVR_NANO_EVERY
#define DEBUG_BAUDRATE 115200
#else
#define DEBUG_BAUDRATE 9600
#endif

/******************************************************************************
 * MCU AND PCB PINS
 ******************************************************************************/

// --- USER SETTINGS: SELECT EXACTLY ONE --------------------------------------
// Use CUSTOM_PINS_DEFINITION only after adding its pin map to PINS_DEF.
// #define CUSTOM_PINS_DEFINITION
// #define SBK_WRIST_BLASTER_PCB_V2
// #define SBK_WRIST_BLASTER_II_PCB_Vx
#define SBK_PROPCORE_ONE_Vx
// #define SBK_PROPCORE_ONE_PLUS_Vx

// --- INTERNAL SETUP / VALIDATION --------------------------------------------
#include "SBK_WRISTBLASTER_PINS_DEF.h"
// Ensure only one PCB is defined
#if (defined(CUSTOM_PINS_DEFINITION) + defined(SBK_WRIST_BLASTER_PCB_V2) + defined(SBK_WRIST_BLASTER_II_PCB_Vx) + defined(SBK_PROPCORE_ONE_Vx) + defined(SBK_PROPCORE_ONE_PLUS_Vx)) != 1
#error "SBK_WRISTBLASTER_CONFIG.h : You must define a PCB, and exactly one PCB type only!"
#endif

/******************************************************************************
 * SWITCHES AND BUTTONS
 ******************************************************************************/

// --- EXTERNAL LIBRARY DEPENDENCY --------------------------------------------
#include <SBK_Button.h>
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

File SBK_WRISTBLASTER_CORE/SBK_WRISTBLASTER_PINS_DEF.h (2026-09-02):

/**
 * @file        SBK_WRISTBLASTER_PINS_DEF.h
 * @brief       Pin definition file for the SBK_WRISTBLASTER_CORE system.
 *
 * @author      Samuel Barabe
 * @copyright   Copyright (c) 2025-2026 Samuel Barabe
 * @license     MIT License
 * @version     2.0.0
 * @link        https://github.com/sbarabe/SBK_WRISTBLASTER
 *
 * @details
 * This file defines all pin assignments for the SBK Wrist Blaster system.
 * Pin mappings are based on the PCB/board type specified in the CONFIG file.
 *
 * Avoid editing this file unless you need to define a custom pin configuration.
 * In all cases, configure your setup through `SBK_WRISTBLASTER_CONFIG.h`.
 *
 * To use a custom pin mapping, define `CUSTOM_PINS_DEFINITION` in your config file.
 *
 * For full setup instructions and documentation, and to support this project, please visit:
 * https://github.com/sbarabe/SBK_WRISTBLASTER
 *
 * @see https://opensource.org/licenses/MIT
 */

#pragma once

/*********************************************/
/*                                           */
/*          MCU PINS CONFIGURATION           */
/*                                           */
/*********************************************/
// See MCU PINS CONFIGURATION section in SBK_WRISTBLASTER_CONFIG.H to select the right board.
// If you don't want to use a pre-defined board pins definition, you can define a custom pins definition below.

/********************************************************/
#if defined(CUSTOM_PINS_DEFINITION)
#pragma message("Compiling for Custom Pins definition.")
// Define your CUSTOM pins definition here :
/********************************************************/
// ARDUINO NANO EVERY PINS DEFINITION
#define PLAYER_SOFTSERIAL // Use software serial for DFPlayer command
#define RX_PIN 2          // If Software Serial is used, SoftSerial receiving pin to audio board Tx pin
#define TX_PIN 3          // If Software Serial is used, SoftSerial transmitting pin to audio board Rx pin
#define BUSY_PIN 12       // Audio player BUSY pin - NOT USED unless BUSY_PIN_READY is enabled. Track lengths are used by default instead of the BUSY signal for faster playback timing.
#define AMP_MUTE_PIN 13   // Onboard Amplifier mute pin
// Bar Meter driver pins
#define PBM_DIN_PIN A4  // connected to bar meter driver DataIn pin / SDA in case of I2C driver
#define PBM_CLK_PIN A5  // connected to bar meter driver Clock pin / SCL in case of I2C driver
#define PBM_LOAD_PIN A3 // connected to bar meter driver Load pin - NOT USED for I2C driver
// WS2812 Leds chain and others leds pins
#define LEDS_STRIP1_PIN A0     // for WS2812 LEDs chain
#define FIRE_BUTTON_LED_PIN 11 // #1 on PCB Switches header, with an in line resistor to protect led : illuminated fire button led output (yellow)
// Buttons and switches
#define FIRE_BUTTON_PIN 10           // #2 on PCB Switches header, should be the Fire Button
#define ACTIVATE_SWITCH_PIN 9        // #3 on PCB Switches header, should be the "Activate" Switch, put Cyclotron in full power for bursts firing
#define CYCLOTRON_POWER_SWITCH_PIN 8 // #4 on PCB Switches header, should be the Top Switch on the gunbox, power the cyclotron and ready to fire.
#define MAIN_POWER_SWITCH_PIN 7      // #5 on PCB Switches header, should be the Bottom Switch on the gunbox, power the blaster to Power On state
#define INTENSIFY_BUTTON_PIN 6       // #6 on PCB Switches header, puts the blaster in party mode, playing themes one after the other. Use fire button to play next.
// SPARE IOs pins on IOs connector
#define SPARE_PIN_IO7 A1 
#define SPARE_PIN_IO8 A2 
// Smoke module pins
#define SMOKE_RELAY_PIN 5  
#define FAN_RELAY_PIN 4   
// Potentiometers input
#define VOL_POT_PIN A6      // For software volume control with audio player
#define FIRE_ROD_POT_PIN A7 // For fire rod hue control

/********************************************************/
// End of CUSTOM PINS DEFINITION section
/********************************************************/
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

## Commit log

2025-02-28 Schematics uploaded
2025-02-28 PCBs dimensions
2025-02-28 SCHEMATICS UPDATES
2025-03-10 Files ranaming and schematic wires colors
2025-03-10 V1 3d model uploaded
    [01-Rod box.stl, 02.1-Gunbox _ smoker.stl, 02.2-Gunbox top indicators leds support.stl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]
2025-03-11 schematics update
2025-03-12 Parts list
    [02.1-Gunbox _ smoker.stl, 02.1-Gunbox.stl, 17A-Clippart valve body.stl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]
2025-03-12 parts lists
    [02-Gunbox ONE PIECE.stl, 02.1-Gunbox.stl, 11-Ggunbox front valve.stl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]
2025-03-19 3d model update
    [02-Gunbox ONE PIECE.stl, 02.3-Gunbox Bar graph support.stl, 07-Gunbox front side panel.stl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]
2025-03-24 Battery holder with PowerCell 3d model update
    [31.1 Battery pack holder 6V-NiMh witch SWITCH.stl, 31.1A Battery pack holder witch KCD1 switch.stl, 31.2 Battery pack holder COVER.stl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]
2025-03-24 3d printed parts list update
2025-03-26 3D models update
    [31.1A Battery pack holder witch KCD1 switch.stl, 31.1C Battery pack holder and 24seg PowerCell.stl, 31.2A Battery pack holder COVER.stl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]
2025-04-01 Update 02.3-Gunbox Bar graph support.stl
    [02.3-Gunbox Bar graph support.stl]
2025-04-01 Update 02-Gunbox ONE PIECE.stl
2025-04-04 3d model corrections and update
    [03-Gunbox base plate A_B version.stl, 03-Gunbox base plate C_D version.stl, 19.2A_.2B-Cyclotron tube filets ring.stl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]
2025-04-04 move files
    [31.1A Battery pack holder witch KCD1 switch.stl, 31.1A Battery pack holder with KCD1 switch.stl, 31.1C Battery pack holder and 24seg PowerCell.stl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]
2025-04-04 Create 32C Main PCB holder (for obsolete gunbox base plate model).stl
    [32C Main PCB holder (for obsolete gunbox base plate model).stl]
2025-04-04 Update 3D printed parts list V1.pdf
2025-04-04 Update 03-Gunbox base plate C_D version.stl
    [03-Gunbox base plate C_D version.stl]
2025-04-22 Change 3300uF for 1500uF on main board
2025-05-06 Update 32B Main PCB holder (SBK PropCore One_OnePlus).stl
    [32B Main PCB holder (SBK PropCore One_OnePlus).stl]
2025-05-08 PCBs guides update
2025-05-08 Armbraced PowerCell battery pack holder
2025-05-26 Parts list and PCBs update
2025-05-26 Schematic update
2025-07-06 Create SBK Wrist Blaster Switches_Buttons desc V0.pdf
2025-11-03 Update 05-Gunbox front panel.stl
    [05-Gunbox front panel.stl]
2025-11-30 31.1C Battery pack holder and 24seg PowerCell v3
    31.1C Battery pack holder and 24seg PowerCell v3
    31.2C Battery pack holder COVER v3
    31.6C has been removed, not necessary anymore
    [29-Vent lens for ONE PIECE GUNBOX.stl, 31.1C Battery pack holder and 24seg PowerCell v2.stl, 31.1C Battery pack holder and 24seg PowerCell v3.stl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]
2026-01-21 Update 01-Rod box.stl
    [01-Rod box.stl]
2026-08-06 3D model V2 added
    [01-Rod box V2.stl, 02-Gunbox ONE PIECE V2 (SBK BarMeter SK28V1).stl, 03-Gunbox base plate for Large arm bracce V2.stl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]
2026-08-06 3d model updates
    [03-Gunbox base plate for Large arm bracce V2.stl, 03-Gunbox base plate for SMALL arm bracce V2.stl, 17A-Clippart valve body.stl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]
2026-08-06 Update README with 2026-08-06 changes
    Added update section for 3D model and electronics boards.
2026-08-06 Revise README with updates on electronics and schematics
    Updated the README to reflect recent changes in the project, including bug fixes and new configurations for electronics boards.
2026-08-27 Update README with firmware v1.1.0 details and images
    Added updates for firmware v1.1.0, including new schematic drawings and features. Improved formatting and added images for better clarity.
2026-08-27 schematic v2.1
